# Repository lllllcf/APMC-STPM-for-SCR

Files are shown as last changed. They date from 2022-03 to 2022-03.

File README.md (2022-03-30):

# Spatial-temporal Programmable Metasurface for Single Channel Radiation

2021 APMC

Exploiting the spatial-temporal relationship, a novel programmable metasurface architecture is proposed to suppress undesired harmonics for spectrally efficient communication. A single-bit metasurface array with four-element unit cells is proposed to allow dynamic beamforming of the information metasurface without the use of phase shifters. The proposed method achieves an array factor with a harmonic suppression ratio of more than 15 dB. The meta-element design operates at a center frequency of 4.3 GHz with a bandwidth of 200 MHz, which can be exploited further to suppress higher-order harmonics. Using a carrier frequency of 4.2 GHz with a 100 MHz modulation signal, the proposed metasurface transmitting a signal with 50 MHz bandwidth can achieve an adjacent channel power ratio of -14.38 dB, indicating the feasibility of spatial-temporal programmable metasurface in practical communication applications.

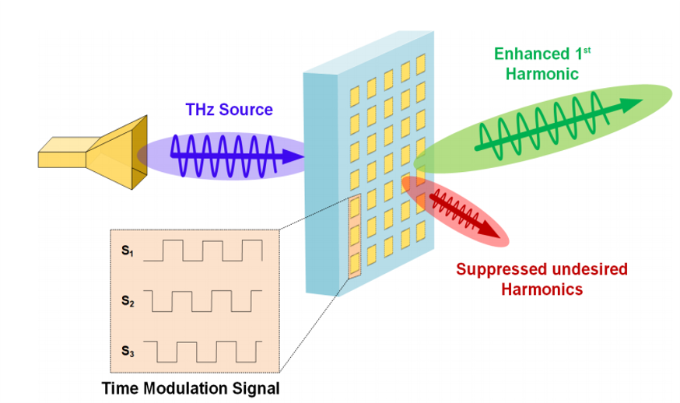
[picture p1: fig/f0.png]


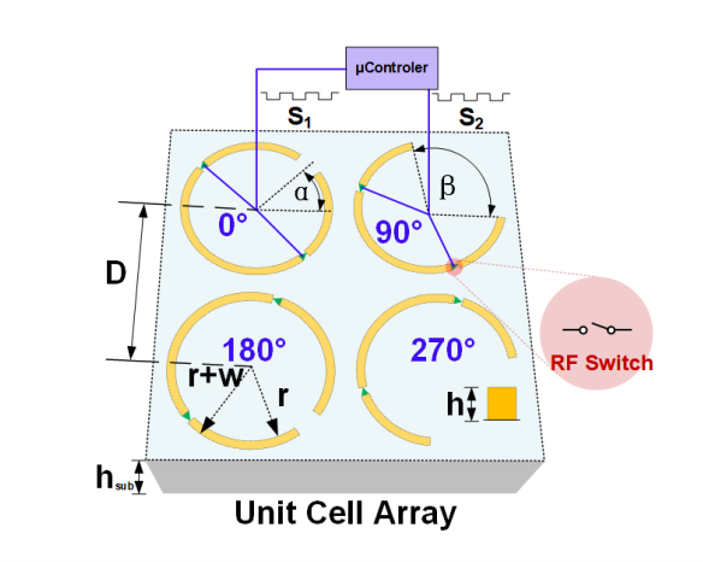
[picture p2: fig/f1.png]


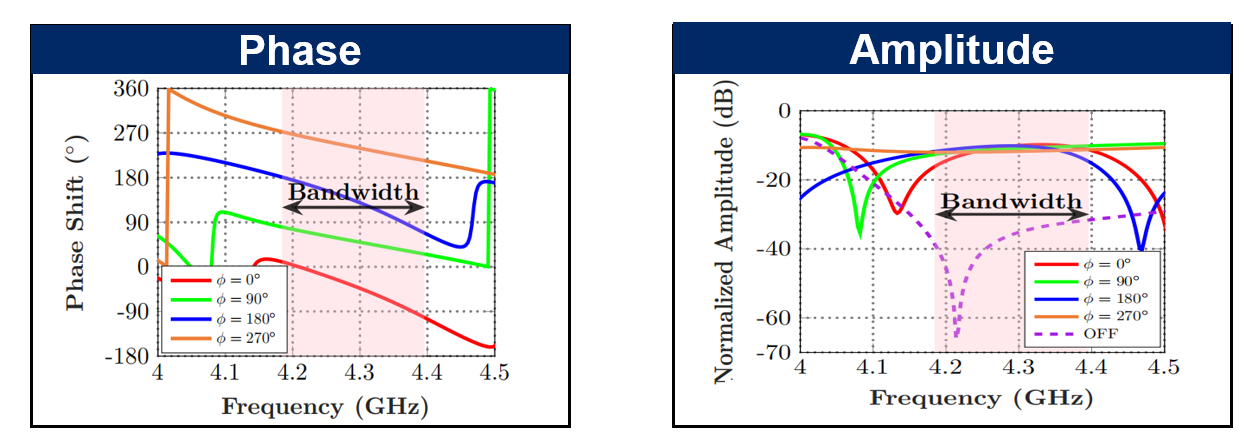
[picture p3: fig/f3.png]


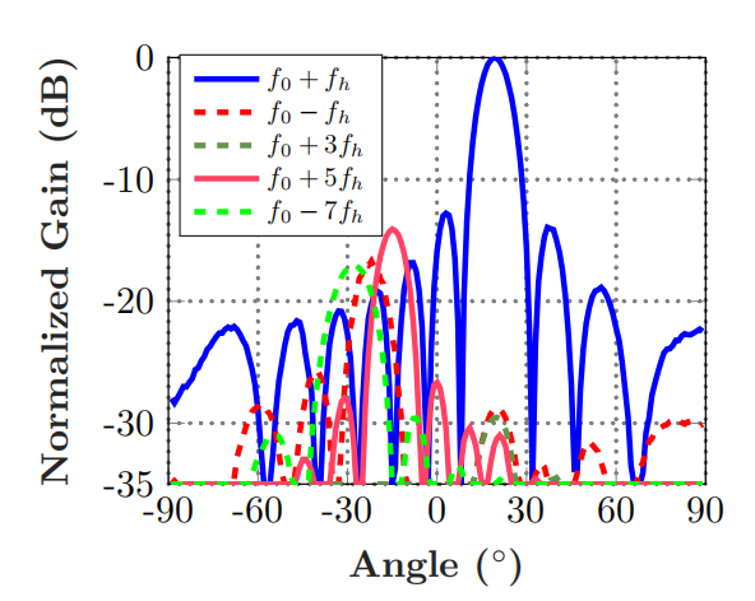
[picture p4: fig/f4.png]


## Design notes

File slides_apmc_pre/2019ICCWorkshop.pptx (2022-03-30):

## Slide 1

A Dynamic Array of Sub-Array Architecture for Hybrid Beamforming in the Terahertz Band

Longfei Yan, Chong Han, and Jinhong Yuan
Terahertz Wireless Communications laboratory
Shanghai Jiao Tong University
Email: longfei.yan@sjtu.edu.cn
Website: http://umji.sjtu.edu.cn/~chan/

## Outline

- Beamforming in the THz band
  - Hybrid (digital + analog)
- The Dynamic Array of Sub-Array (DAoSA) Hybrid Beamforming Architecture
- Summary

## The Terahertz Band

- Right after the mm-waves: from 0.1 to 10 THz
- Provides huge bandwidth: multiple GHz and even THz

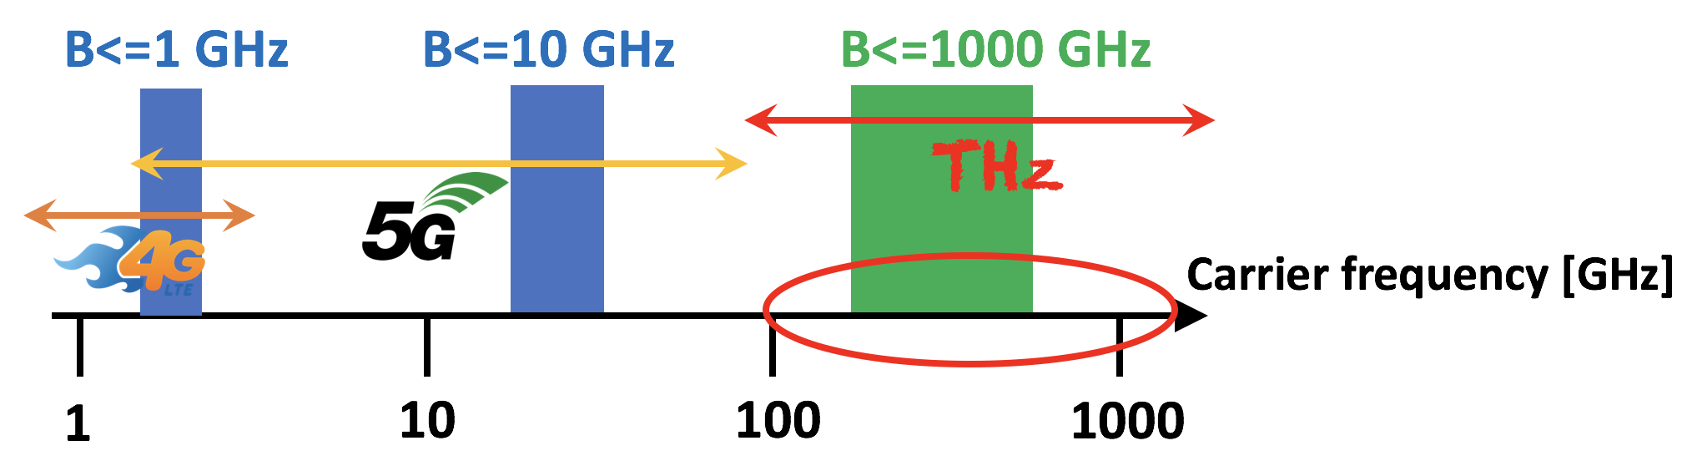
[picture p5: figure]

100 Gbps or even 1 Tbps is possible

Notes: Instead, lets take a look at the THz band, which lies right after the mm-wave. THz band is from 0.1 to 10 THz. It can provide multiple GHz and even THz bandwidth. This huge bandwidth of terahertz spectrum makes Tbps wireless link possible.

## Distance Challenge

I. F. Akyildiz, C. Han*, and S. Nie,
“Combating the Distance Problem in the Millimeter Wave and Terahertz Frequency Bands”,
IEEE Communications Magazine, 2018

- Distance limitation: a major challenge at THz frequencies is posed by the very high propagation loss
- Reasons:
  - Spreading loss
  - Molecular absorption loss
  - Reflection and scattering loss

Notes: Spreading loss: increases quadratically with the frequency, as defined by Friis’ law
Molecular absorption loss: part of the wave energy is converted into internal kinetic energy of the medium molecules (e.g., water-vapor)
Reflection and scattering loss: rough surface scattering arises with tens of dB losses

## Ultra-Massive MIMO

Frequency: f ↑

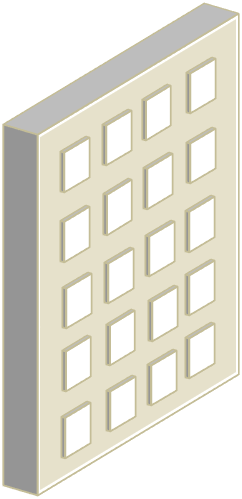
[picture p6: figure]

Smaller wavelength

More antennas

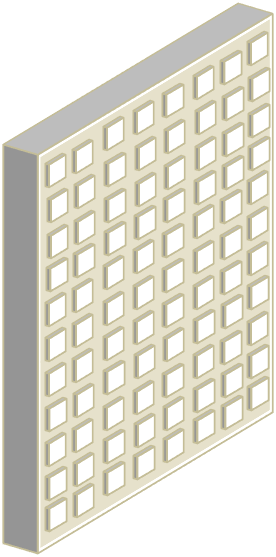
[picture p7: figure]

THz: f=1 THz, λ=0.3mm → Ultra-Massive MIMO, e.g., 256, 512 or even 1024 antennas at transmitter and receiver

Number of antennas: N ↑

How can we use these ultra-massive antennas to get benefits?

One solution is beamforming!

## Beamforming

Beamforming (BF) is to focus the radiated power of the antenna array into one or multiple directions.
Combined with the UM-MIMO system, the BF can provide:
- Array gain ∝ N_t N_r to increase the received SNR
- Spatial Multiplexing gain ∝ N_p to further enhance the spectral efficiency
- A Promising technology in THz wireless communications

## Why hybrid?

Digital beamforming: hardware & power consumption ✘

FPGA
+
DSP

FPGA
+
DSP

DAC

RF
Chain

RF
Chain

ADC

Channel
Matrix

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
Chain

RF
Chain

ADC

digital precoder

digital combiner

## Why hybrid?

Analog beamforming: performance & only single data stream ✘

Baseband

DAC

RF
Chain

N_t

Channel
Matrix

N_r

RF
Chain

ADC

Baseband

analog precoder

analog combiner

## Why hybrid?

Hybrid analog and digital beamforming:

FPGA
+
DSP

DAC

RF
Chain

Analog
signal
processing

analog precoder

N_s

L_t

DAC

RF
Chain

N_t

digital precoder

Analog
signal
processing

analog combiner

RF
Chain

FPGA
+
DSP

ADC

N_r

RF
Chain

L_r

ADC

N_s

digital combiner

Channel
Matrix

1≤L_r ≪ N_r

1≤L_t ≪ N_t

## Fully-Connected (FC)

FPGA
+
DSP

DAC

RF
Chain

RF
Chain

ADC

FPGA
+
DSP

N_t

Channel
Matrix

L_r

ADC

N_s

L_t

DAC

RF
Chain

N_r

RF
Chain

N_s

digital precoder

analog precoder

analog combiner

digital combiner

Each RF chain connects to all antennas through phase shifters.
The spectral efficiency can approach that of the digital beamforming.

O. E. Ayach, S. Rajagopal, S. Abu-Surra, Z. Pi, and R. W. Heath, “Spatially Sparse Precoding in Millimeter Wave MIMO Systems,” IEEE Trans. Wireless Commun, vol. 13, no. 3, pp. 1499–1513, March 2014.

## Array of Sub-array (AoSA)

FPGA
+
DSP

DAC

L_t

RF
Chain

N_t /L_t

N_r /L_r

RF
Chain

ADC

FPGA
+
DSP

Channel
Matrix

N_s

DAC

RF
Chain

N_t /L_t

N_t

N_r

N_r /L_r

RF
Chain

L_t

ADC

N_s

digital precoder

analog precoder

analog combiner

digital combiner

Each RF chain only connects to a sub-array through phase shifters.
Poor performance on spectral efficiency.

R. W. Heath and N. G.-P. et al, “An Overview of Signal Processing Techniques for Millimeter Wave MIMO Systems,”
IEEE J. Sel. Topics Signal Process, vol. 10, no. 3, pp. 436–453, April 2016.

## FC and AoSA architectures

- FC and AoSA

| Power consumption | Spectral efficiency
FC | Higher | Better
AoSA | Lower | poorer

Sacrifice either power consumption or spectral efficiency

Can we achieve a comparable spectral efficiency compared with FC while consuming much less energy?

Our solution: The dynamic array of sub-array (DAoSA) architecture

## Outline

- Beamforming in the THz band
  - Hybrid (digital + analog)
- The Dynamic Array of Sub-Array (DAoSA) Hybrid Beamforming Architecture
- Summary

## Dynamic Array of Sub-Array

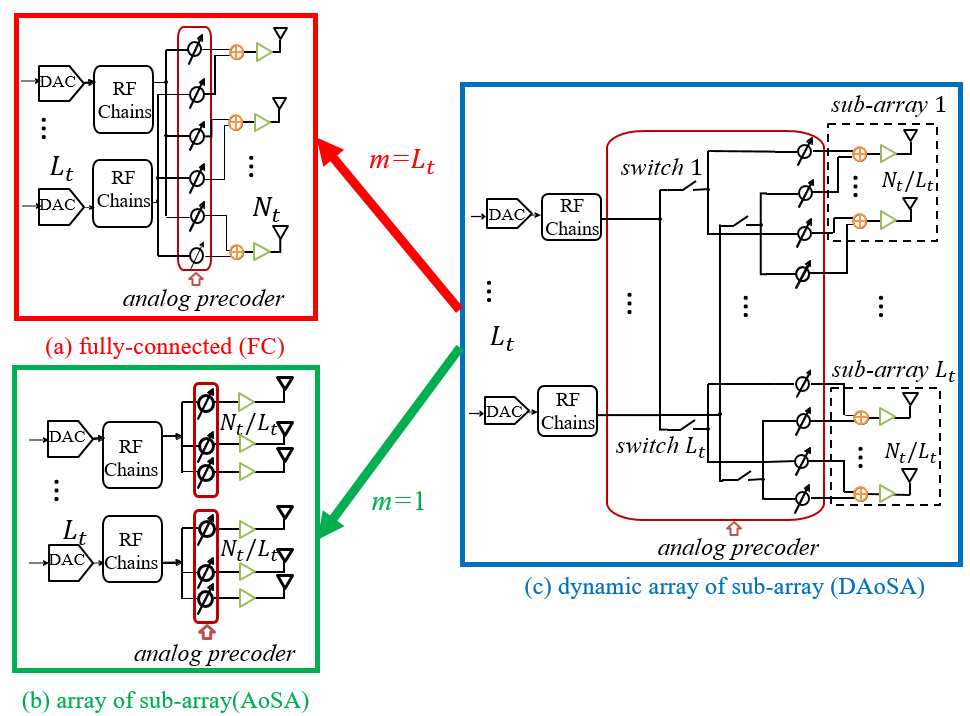
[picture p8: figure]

- Divide the antennas into L_t sub-arrays.
- Each RF chain connects to all the sub-arrays through L_t switches, but only m switches are closed.

- Antennas: N_t
- RF chains: L_t
- Switches: (L_t )^2
- Closed switches: m L_t
- Phase shifters: m N_t

## Problem Formulation

- Maximize the spectral efficiency
When assuming the Gaussian symbols, the spectral efficiency achieved by UM-MIMO systems can be stated as
- R_n =σ_n^2 C_D^H C_A^H C_A C_D is the covariance matrix of the noise vector after combining.
- The essence of solving this problem is finding proper P_A , P_D and C_A , C_D to maximize the spectral efficiency.

R=log_2 (|I_(N_s) +ρ/(N_s)R_n^(−1) C_D^H C_A^H HP_A P_D ×P_D^H P_A^H H^H C_A C_D | ),

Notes: After introducing the J2SMB system and the architecture, we are interested about the problem formulation and the solution of J2SMB system.

## Optimization Solution

Put the receiver optimal then optimize the transmitter side.
After designing the transmitter side, the receiver side can be designed as the same method.
P_A and P_D can be solved by

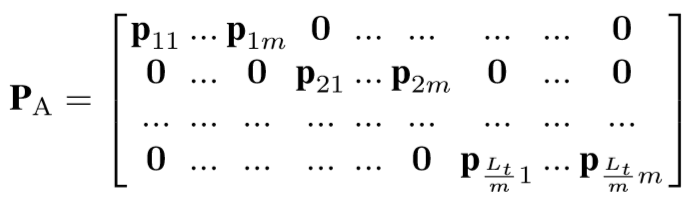
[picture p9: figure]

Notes: However, the joint optimization about transmitter and receiver is extremely difficult. To simplify the optimization process, first we make the assumption that the receiver is optimal so that we can focus on the design of transmitter. After determining the P_A and P_D , we solve the C_A and C_D . The optimization about transmitter and receiver is similar, so we give the optimization solution of P_A and P_D as an example and omit the optimization at receiver.

However, the joint optimization about transmitter and receiver is extremely difficult. To simplify the optimization process, first we make the assumption that the receiver is optimal so that we can focus on the design of transmitter. After determining the P_A and P_D, we solve the C_A and C_D. The optimization about transmitter and receiver is similar, so we give the optimization solution of P_A and P_D as an example and omit the optimization at receiver.

## Optimization Solution

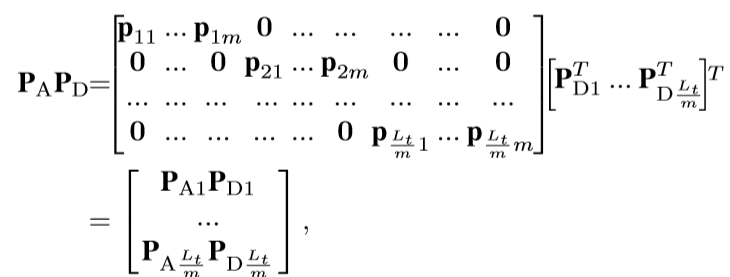
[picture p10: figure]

One intractable DAoSA problem has been decomposed into multiple tractable FC problems.
We just need to solve these FC problems one by one and then compose the ultimate solution.

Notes: However, the joint optimization about transmitter and receiver is extremely difficult. To simplify the optimization process, first we make the assumption that the receiver is optimal so that we can focus on the design of transmitter. After determining the P_A and P_D , we solve the C_A and C_D . The optimization about transmitter and receiver is similar, so we give the optimization solution of P_A and P_D as an example and omit the optimization at receiver.

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

## Performance Evaluation

- Simulation parameters

N_t = N_r =256, L_t = L_r =8, N_p ≤ 20, N_s =2 or 4

N_t and N_r : the number of antennas at transmitter and receiver
L_t and L_r : the number of RF chains at transmitter and receiver
N_p : the number of multi-path of the THz UM-MIMO channel
N_s : the number of data streams

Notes: Nt and Nr are the number of transmit antennas and receive antennas respectively. Lt and Lr are the number of RF chains at transmitter and receiver. Nray is the number of paths which make up the channel matrix H. m and n are the dynamic parameters of the DAoSA architecture.

## Power Consumption

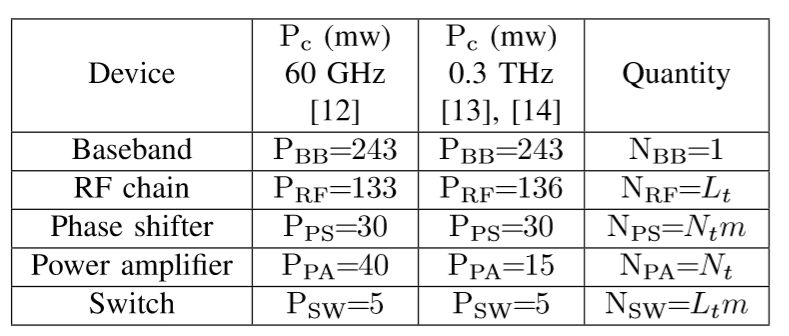
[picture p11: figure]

P_(total) =P_(BB) N_(BB) +P_(RF) N_(RF) +P_(PS) N_(PS) +P_(PA) N_(PA) +P_(SW) N_(SW)
= (a+b×m)%×P_total_FC
≈ (10 + 11m)% ×P_total_FC

## Spectral efficiency

DAoSA(Ns=4,m=4): similar SE, consume only 54% power

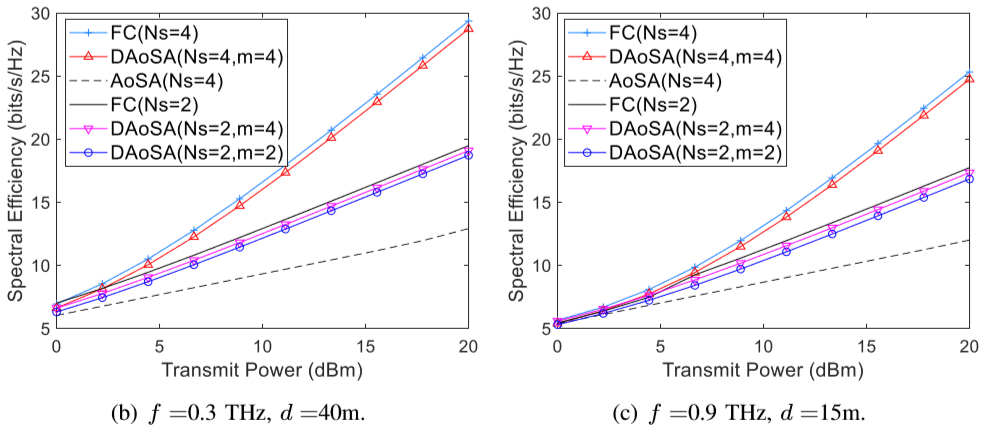
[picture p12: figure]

DAoSA(Ns=2, m=2):similar SE, consume only 32% power

The spectral efficiency of DAoSA is fairly closed to that of the FC and much higher than the AoSA.

(10 + 11m)% ×P_total_FC

## Outline

- Beamforming in the THz band
  - Hybrid (digital + analog)
- The Dynamic Array of Sub-Array (DAoSA) Hybrid Beamforming Architecture
- Summary

## Summary

Through selecting m intelligently, the spectral efficiency of DAoSA architecture is fairly closed to that of the FC, while consuming less power.
Compared with the AoSA architecture, the substantially higher spectral efficiency makes DAoSA more appealing.

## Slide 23

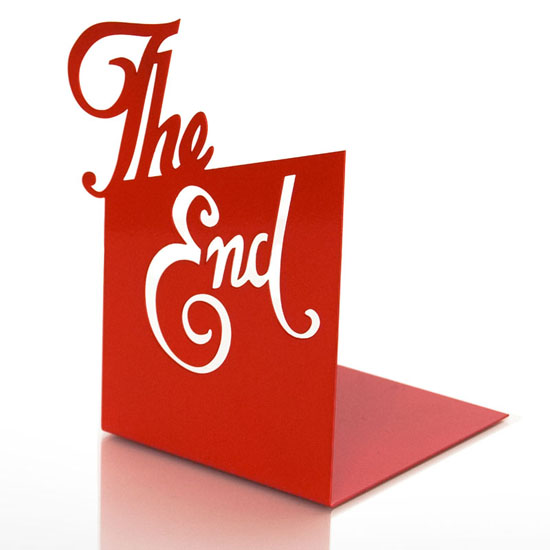
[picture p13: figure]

Mr. Longfei Yan
University of Michigan-Shanghai Jiao Tong University Joint Institute
Shanghai Jiao Tong University
Shanghai, 200240, China
Email: longfei.yan@sjtu.edu.cn
Website: http://umji.sjtu.edu.cn/~chan/

## CBC algorithm

Goal: minimize
Hint: there are l_t columns in P_(Ai) , N_s columns in P_(opti) .
First, divide the columns of P_(opti) into two groups. The exact group has l_t - N_s columns. The approximated group has 2 N_s - l_t columns.
Exact group: each column is exactly expressed as
Approximated group: each column is approximated as
Then, construct P_(Ai) and P_(Di) .

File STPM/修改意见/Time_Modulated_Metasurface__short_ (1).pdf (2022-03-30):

# High Efficiency beamforming Based on Time-Modulated Programmable Metasurface

Chengfan Li∗

, Zhehao Yu∗

, Yan Shen†

, Runqing Cai∗

, Xuyang Lu∗

∗UM-SJTU Joint Institute, Shanghai Jiao Tong University, Shanghai 200240, China †School of Electronics and Information Technology, Sun Yat-sen University, Guangzhou 510275, China Corresponding author: xuyang.lu@sjtu.edu.cn

Abstract—In this paper, a time-modulated programmable metasurface structure and its corresponding control strategy is designed to achieve beamforming and undesired harmonics suppression.
Index Terms—Beamforming, Harmonic Suppression, Programmable Metasurface, Time-Modulated Array.
I. Introduction

Recently, metasurfaces have attracted significant research interests due to its capability of tailoring the electromagnetic characteristics such as polarization, phase and amplitude at ease allows for the realization of beamforming [1] and frequency-division multiplexing [2]. As for metasurface beamforming, to make the control of EM waves more flexible, the active metasurface adds one or more switches on the metasurface structure, each switch brings two different states for active metasurface. More states means that the beam direction can be adjusted by switches, but it also increases the harmonic waves, leading to the efficiency degradation. Therefore, active metasurface faces the trade-off between flexibility and efficiency, especially in beamforming.
On the other hand, beamforming is achieved through the time-modulated array by exploiting time-domain signal processing techniques [3]. To achieve a low sideband level (SBL), the switching sequence can be designed such that a combination of signals modulated by those pulses will lead to suppression of undesired harmonics [4]. Therefore, it is a possible solution to construct flexible and efficient metasurface by applying the time modulation technique.
In this paper, as shown on Fig. 1, a time-modulated programmable metasurface (TMPM) is designed to receive external time modulation pulse signals to control the fast switching of each switch independently, so as to achieve beamforming and harmonic suppression. Each unit structure has four "ON" states with phase shift ϕ = (0, π
2

,π,

3π
2

)
and one "OFF" state with low transmittance. To apply time modulation method, a unit structure of four 1-bit metasurface unit cells are implemented to provide different phase shifts, and then combine them together to form a metasurface array.

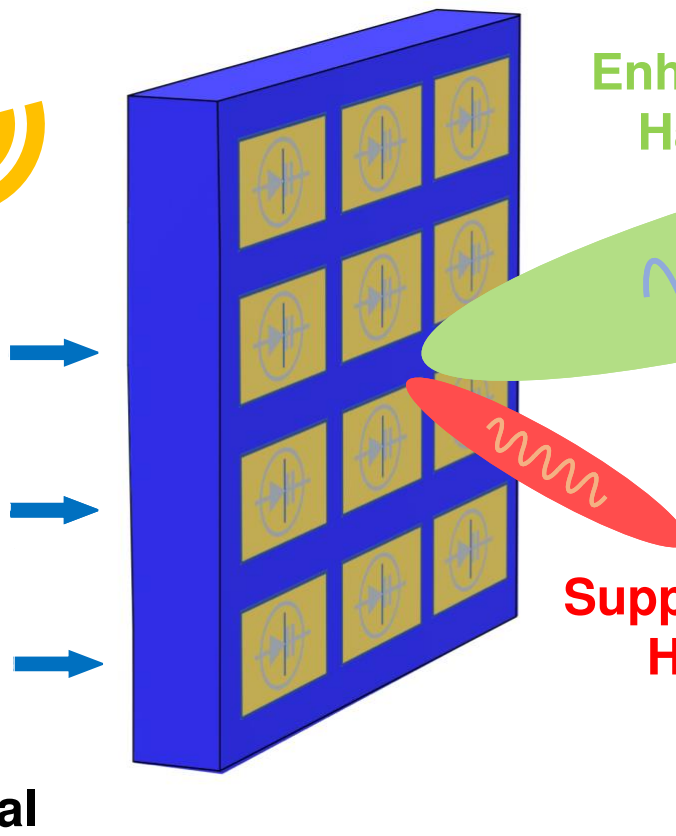
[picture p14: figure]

Suppressed other
Harmonics

Enhanced 1st
Harmonic

S1

S3

S2

Time Modulation Signal

Source

Fig. 1. Architecture of TMPM. Different time modulation signals are designed for each metasurface unit cell to achieve beamforming and suppress undesired harmonics.

II. Design and Theory
A. Time Modulated Metasurface Principle
To achieve high efficiency beamforming, time modulation control sequence for each switch should be designed. In this section, modulation sequence of metasurface with negligible inter-cell distance is first considered and then the impact of the distance is further calculated.
The length of each metasurface unit structure is defined as λ/D. As mentioned earlier, in ideal situation, each unit structure can be viewed as an array element which means that the distance λ/2D between two unit cells vanishes. Suppose that the origin is defined at the center of the bottom left unit structure and the whole metasurface totally have M rows and N columns, then the position of the unit structure on the mth row and n

th column under
the ideal case can be defined as
dmn = (mλ/D, nλ/D, 0). | (1)

Therefore, the array factor can be expressed as

AF(θ, ϕ, t) = f(t)

∑

M

m=1

∑

N

n=1

Imn · Umn

- e

j

2π
D sin θ[(m−1) cos ϕ+(n−1) sin ϕ]
(2)

where θ and ϕ defines the aimed angle for beamforming, ,f(t) denotes the incident wave, Imn is the transmittance for the unit structure on position dmn and Umn is the control function for the unit structure on position dmn. Because each unit structure contains four unit cells, Umn can be further expressed as

Umn = U

0
mn(t) + jU

π
2mn(t) − U

π
mn(t) − jU

3π
2mn(t) (3)

where U

0
mn(t), U

π
2mn(t), U

π
mn(t) and U

3π
2mn(t) are control
function on unit cell with different phases. Because those control functions consist of square wave, therefore U

i
| mn(i =
0,

π
2

, π, 3π
2

) can be further expressed as

Umn,i(t) = rect(

t − τ /2 − kTp − t

i
mn
τ
) | (4)

where Tp is the period of the switch control signal, τ is the time when the switch is on and t

i
mn is the time delay. The
four cells’ time delay and τ are designed as

t

π
2mn = t

0
mn +

Tp
4

t

π
mn = t

0
mn +

Tp
2

t

3π
2mn = t

0
mn −

Tp
4

τ =

Tp
3

(5)

where

t

0
mn = {

sin θ
D

[(m − 1) cos ϕ + (n − 1) sin ϕ] −

1
6

}Tp. (6)

To consider the impact of the interval between unit cells. A function f∆(x, y) can be defined to represent the time delay caused by the unit cell with position deviation (x, y) relative to the center of unit metasurface structures.

f∆(x, y) = |(x − 1) sin θ cos ϕ + (y − 1) sin θ sin ϕ − cos θ| − |sin θ cos ϕ + sin θ sin ϕ + cos θ| . (7)
For the relative position of the four unit cells related to the center of the unit metasurface structure is fixed, the advance of time can be defined as positive and the delay of time can be defined as negative. Therefore, f∆(x, y) can be modified into
f∆(x, y) = −x sin θ cos ϕ − y sin θ sin ϕ. | (8)

Then the equation for modifying the four tmn,i functions (i = 0,

π
2

, π, 3π
2

) can be simplified into a more general form with the value of τ remains unchanged.

t

i

′
mn = t

i
mn − f∆(xi
, yi) | (9)

where i = 0,

π
2

, π, 3π
2

and (xi

, yi) is the relative position of each unit cell, for example, (x0, y0) = (−

λ
4D

,

λ
4D

).

B. Unit Metasurface Structure Design
In this section, four 1-bit C-shape programmable metasurface unit cells with different phase responses are de-

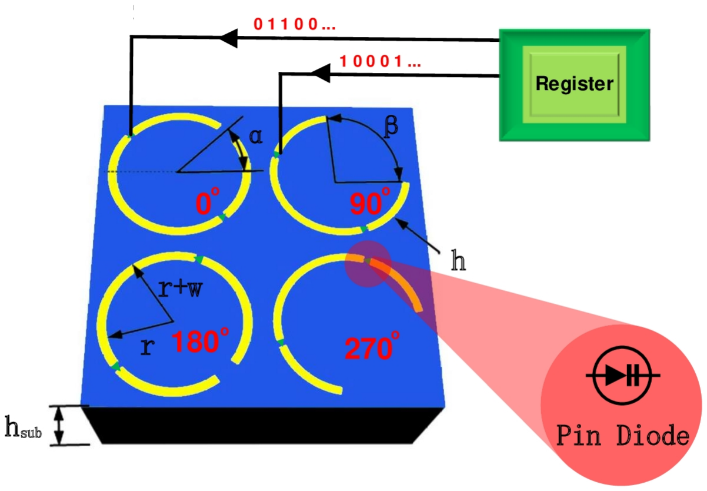
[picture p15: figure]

Fig. 2. Structure of C-shape metasurface unit structure with h={0.035, 0.018, 0.035, 0.018} mm, w={0.96, 0.84, 0.96, 0.84} mm, β={18, 108, 18, 108}◦, α={45, 45, -45, -45}◦, r=7.2 mm and hsub=16 mm. Here the four parameters of all the data correspond to the unit cell perform 0,

| π
| 2 , π, 3π
| 2 phase shift. Each unit cell contains two pin
diodes controlled by the time modulation signals.

signed and form a metasurface unit structure. The improved structure is shown on Fig. 2. On the top layer is four thin copper rings with height h, inner diameter r and thickness w. Under the ring is a substrate with thickness hsub, side length λ/D and dielectric constant 3.66. Two MA4AGFCP910 pin diodes produced by MACOM are added on each metal ring to realize the programmable function, and FPGA is used to control the fast switch of each unit cell independently to realize the time modulation. Through the design of opening angle β and orientation angle α towards the x-axis, phase modulation can be realized. When just one unit cell is opened, the unit structure produces phase response corresponding to that of the unit cell. Therefore, four "ON" states with different phase shifts can be achieved by open one unit cell and through closing all the pin diodes, "OFF" state can be produced.
Simulation results performed through CST Microwave Studio is shown on Fig. 3(a) and Fig. 3(b), which show the transmittance and phase shift responses of the unit structure. At the operating frequency, 4.21GHz, the simulation results show that there exists about 45dB difference on transmittance difference between four "ON" states and the ’OFF’, and four phases with separation of approximately
π
2

in the four "ON" states.

III. Simulation Result

Simulation is performed to validate the TMPM method with T=4, targeted angle ...◦ and operating frequency 4.21GHz. In order to simulate the ability of the TMPM to form beam and suppress spurious bands, a binary image is modulated and transmitted through the time modulated metasurface.
Fig. 3(c) gives a pictorial representation of the switch control signal of twelve metasurface unit cells at the posi-

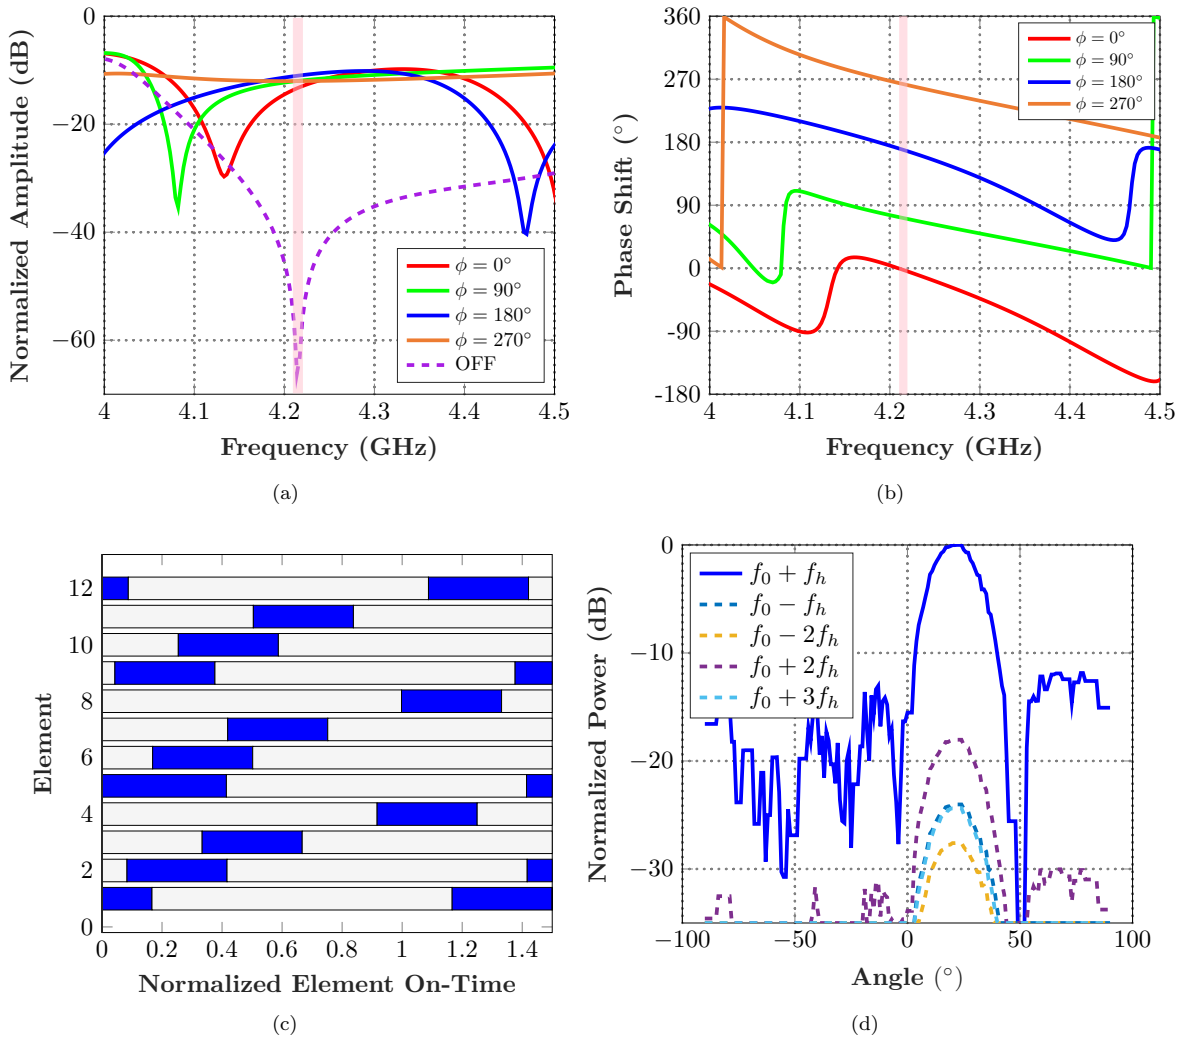
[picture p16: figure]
Frequency (GHz); Normalized Amplitude (dB); OFF; Phase Shift (; Normalized Element On-Time; Element; Angle (; Normalized Power (dB)

Fig. 3. Simulated characteristics of unit metasurface structure. (a) The S21 parameter of the five states. From 4.19GHz to 4.39GHZ, the S21 parameter for "ON" states is larger than -13dB and S21 parameter for the "OFF" state is less than -30dB. And the minimal amplitude response for "OFF" state is -66dB. (b) The four different phase shift responses. From 4.14GHz to 4.35GHz, the average relative error angle is less than 10◦. (c) The switch control signal for TMPM where blue means the pin diode is on. (d) Simulated radiation patterns for different harmonics generated by TMPM.

tion d11, d12 and d13. The periodicity of the switch control
signal and the offset between different unit structures can be clearly observed. Fig. 3(d) shows the normalized power on five different harmonics. The normalized power of the side band are all less than ...dB and the power of the 1st harmonic reaches the maximum at our target angle.

IV. Conclusion

In this paper, a time modulated programmable metasurface structure and its corresponding control strategy is designed to ensure both flexibility and efficiency of beamforming and spurious bands suppression. The validity of the metasurface structure containing four "ON" states with different phase responses and one "OFF" state with low transmittance is shown by CST simulation and the control strategy of the metasurface array is tested by MATLAB which shows accurate beamforming and effective harmonic suppression abilities.

References

[1] S. Liu, T. J. Cui, L. Zhang, Q. Xu, Q. Wang, X. Wan, J. Q. Gu, W. X. Tang, M. Qing Qi, J. G. Han et al., “Convolution operations on coding metasurface to reach flexible and continuous controls of terahertz beams,” Advanced Science, vol. 3, no. 10, p. 1600156, 2016.
[2] L. Zhang, M. Z. Chen, W. Tang, J. Y. Dai, L. Miao, X. Y. Zhou,
S. Jin, Q. Cheng, and T. J. Cui, “A wireless communication scheme based on space-and frequency-division multiplexing using digital metasurfaces,” Nature Electronics, vol. 4, no. 3, pp. 218– 227, 2021.

[3] H. Shanks and R. Bickmore, “Four-dimensional electromagnetic radiators,” Canadian Journal of Physics, vol. 37, no. 3, pp. 263– 275, 1959.
[4] A.-M. Yao, W. Wu, and D.-G. Fang, “Single-sideband time-modulated phased array,” IEEE Transactions on Antennas and Propagation, vol. 63, no. 5, pp. 1957–1968, 2015.

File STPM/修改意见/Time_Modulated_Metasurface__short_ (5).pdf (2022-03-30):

# High Efficiency beamforming Based on Time-Modulated Programmable Metasurface

Chengfan Li, Yan Shen, Zhehao Yu, Runqing Cai, Xuyang Lu

School of Electronics and Information Technology, Sun Yat-sen University, Guangzhou 510275, China UM-SJTU Joint Institute, Shanghai Jiao Tong University, Shanghai 200240, China. Corresponding author: xuyang.lu@sjtu.edu.cn

Abstract—In this paper, a time-modulated transmitive programmable metasurface structure and its corresponding control strategy is designed to achieve beamforming and spurious bands suppression.
Index Terms—Programmable Metasurface, Time-Modulated Array, Single-Sideband.
I. Introduction
Recently, metasurface have received wide attention due to its ability to manipulate electromagetic waves by controlling the polarization conversion, phase shift and amplitude response of electromagnetic waves. Many applications including beamforming, wireless communication, hologram and encryption have made great progress[...]. Focus on the area of metasurface beamforming, there are two kinds of metasurfaces: passive and active. Each unit of passive metasurface has only one response mode, so after periodic arrangement, the beam can only form on a specific direction. The active metasurface adds one or more switches on the metasurface structure, each switch brings two different states for active metasurface, and the formed wave can direct to many different directions. During this process, metasurface faces the trade-off between flexibility and efficiency, especially in beamforming. More states means that the beam direction can be adjusted by switches, but it also increases the harmonic waves, leading to the efficiency degradation.
So how to use active metasurface with less states to realize beamforming and suppress harmonics to ensure flexibility and efficiency at the same time becomes an important problem. In this context, beamforming achieved through the time-modulated array by exploiting timedomain signal processing techniques [1] becomes a potential solution. To achieve a low sideband level (SBL), the switching sequence can be designed such that a combination of signals modulated by those pulses will lead to suppression of undesired harmonics [2].
In this paper, as shown on Fig. 1, a time-modulated programmable metasurface (TMPM) is designed to receive external time modulation pulse signals to control the fast switching of each switch independently, so as to achieve beamforming and harmonic suppression. Each unit structure has four ’ON’ states with phase shift ϕ = (0, π
2

,π,

3π
2

)
and one ’OFF’ state with low transmittance. To apply

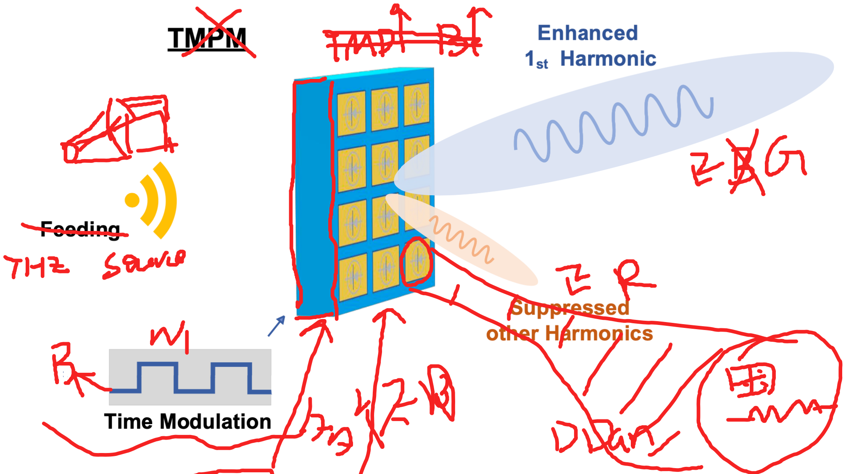
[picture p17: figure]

Fig. 1. Architecture of TMPM.

time modulation method, a unit structure of four 1-bit metasurface unit cells are implemented to provide different phase shifts, and then combine them together to form a metasurface array.

II. Design and Theory

A. Time Modulated Metasurface Principle

To achieve high efficiency beamforming, time modulation control sequence for each switch should be design. In this section, modulation sequence of metasurface with negligible inter-cell distance will first be considered and then the impact of the distance will be further calculated. The length of each metasurface unit structure is defined as λ/D. As mentioned earlier, in ideal situation, each unit structure can be viewed as an array element which means that the distance λ/2D between two unit cells vanishes. Suppose that the origin is defined at the center of the bottom left unit structure and the whole metasurface totally have M rows and N columns, then the position of the unit structure on the mth row and n

th column under
the ideal case can be defined as
dmn = (mλ/D, nλ/D, 0). | (1)

So the array factor can be written as

AF(θ, ϕ, t) = f(t)

∑

M

m=1

∑

N

n=1

Imn · Umn

- e

j

2π
D sin θ[(m−1) cos ϕ+(n−1) sin ϕ]
(2)
where θ and ϕ defines the aimed angle for beamforming, ,f(t) denotes the incident wave, Imn is the transmittance for the unit structure on position dmn and Umn is the control function for the unit structure on position dmn. Because each unit structure contains four unit cells, Umn can be further written as

Umn = U

0
mn(t) + jU

π
2mn(t) − U

π
mn(t) − jU

3π
2mn(t) (3)

where U

0
mn(t), U

π
2mn(t), U

π
mn(t) and U

3π
2mn(t) are control
function on unit cell with different phases.
The control signal consists of square wave so that the control functions U

i
mn(i = 0,

π
2

, π, 3π
2

) can be further
writtern as

Umn,i(t) = rect(

t − τ /2 − kTp − t

i
mn
τ
) | (4)

where Tp is the period of the switch control signal, τ is the time when the switch is on and t

i
mn is the time delay.
For each unit structure, the four cells’ time delay and τ can be writtern as

t

π
2mn = t

0
mn +

Tp
4

t

π
mn = t

0
mn +

Tp
2

t

3π
2mn = t

0
mn −

Tp
4

τ =

Tp
3
where

t

0
mn = {

sin θ
D

[(m − 1) cos ϕ + (n − 1) sin ϕ] −

1
6

}Tp. (5)

To consider the impact of the interval between unit cells. A function can be defined f∆(x, y) to represent the time delay caused by the unit cell position deviation (x, y).

f∆(x, y) = |(x − 1) sin θ cos ϕ + (y − 1) sin θ sin ϕ − cos θ| − |sin θ cos ϕ + sin θ sin ϕ + cos θ| . (6)

For the relative position of the four unit cells related to the center of the unit metasurface structure is fixed, we can suppose that the advance of time is defined as positive and the delay of time is defined as negative. So that f∆(x, y) can be modified into

f∆(x, y) = −x sin θ cos ϕ − y sin θ sin ϕ. | (7)

Then the equation for modifying the four tmn,i functions (i = 0,

π
2

, π, 3π
2

) can be simplified into a more general form.

And the value of τ remains unchanged.

t

i

′
mn = t

i
mn − f∆(xi
, yi) | (8)

where i = 0,

π
2

, π, 3π
2

, (xi

, yi) is the relative position of each unit cell, for example, (x1, y1) = ( λ
4D

,

λ
4D

).

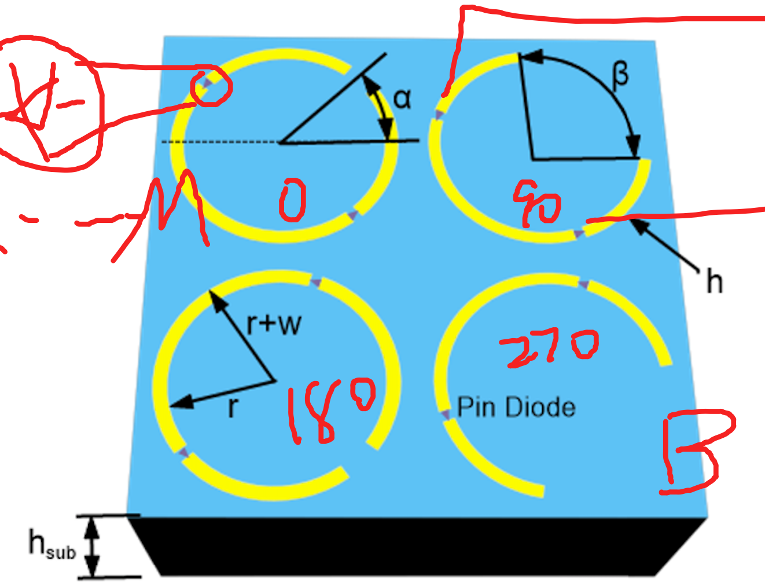
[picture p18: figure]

Fig. 2. Structure of C-shape metasurface unit structure with h={0.035, 0.018, 0.035, 0.018} mm, w={0.96, 0.84, 0.96, 0.84} mm, β={18, 108, 18, 108} ◦, α={45, 45, -45, -45} ◦, r=7.2 mm and hsub=16 mm. Here the four parameters of all the data correspond to the unit cell perform 0, π

| 2 ,π, 3π
| 2 phase shift.
B. Unit Metasurface Structure Design
In this section, four 1-bit C-shape programmable metasurface unit cells are designed and form a metasurface unit structure. The improved structure is shown on Fig.
2. On the top layer is four thin copper rings with height h, inner diameter r and thickness w. Under the ring is a substrate with thickness hsub, side length λ/D and dielectric constant 3.66 Two MA4AGFCP910 pin diodes produced by MACOM are added on each metal ring to realize the programmable function, and FPGA is used to control the fast switch of each unit cell independently to realize the time modulation. Through the design of opening angle β and orientation angle α towards the xaxis, phase modulation can be realized.
Simulation results performed through CST Microwave Studio is shown on Fig. 3, which shows the transmittance and phase shift responses of the unit structure. At the operating frequency, 4.21GHz, the simulation results show that there exists about 45dB difference on transmittance difference between four ’ON’ states and the ’OFF’, and four phases with separation of approximately π
| 2

in the four
’ON’ states.

III. Simulation Result
Simulation is performed to validate the TMPM method with T=4, targeted angle 20◦ and operating frequency 4.21GHz. In order to simulate the ability of the TMPM to form beam and suppress spurious bands, a binary image is modulated and transmitted through the time modulated metasurface.
Fig. ?? gives a pictorial representation of the switch control signal of twelve metasurface unit cells at the position d11, d12 and d13. The periodicity of the switch control signal and the offset between different unit structures can

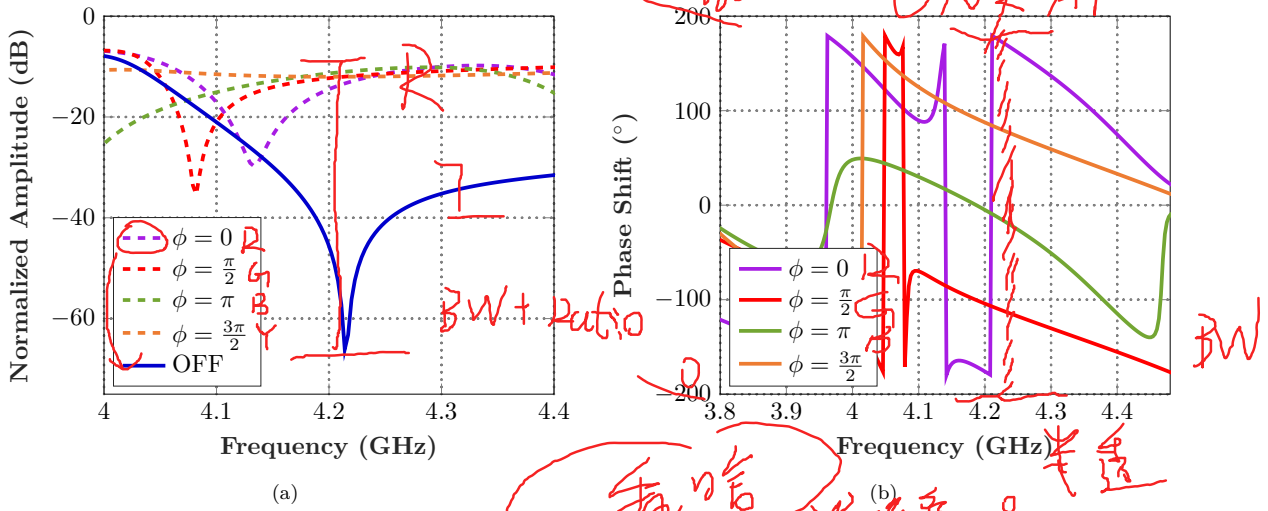
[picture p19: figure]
Frequency (GHz); Normalized Amplitude (dB); OFF; Phase Shift (

2 | 4 | 6 | 8 | 10 | 12

0

0.5

1

1.5

Element

Normalized Element On-Time

(c)

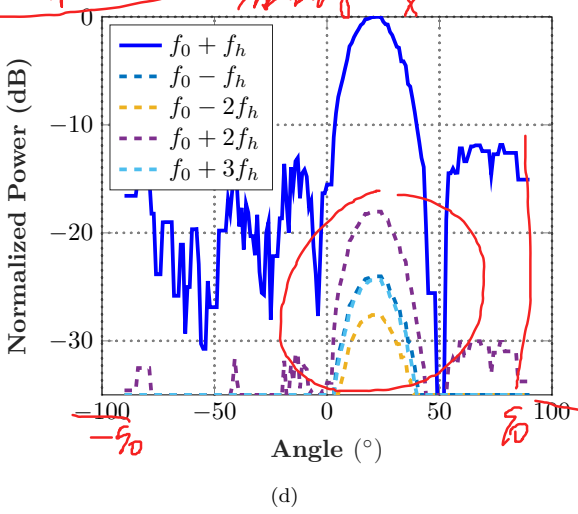
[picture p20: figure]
Angle (; Normalized Power (dB)

Fig. 3. Simulated characteristics of unit metasurface structure. (a) The S12 parameter of the five states. (b) The four different phase shift responses.

be clearly observed. Fig. ?? shows the normalized power
on five different harmonics. The normalized power of the side band are all less than -18dB and the power of the 1st harmonic reaches the maximum at our target angle.

IV. Conclusion
In this paper, a time modulated transmitive programmable metasurface structure and its corresponding control strategy is designed to achieve beamforming and spurious bands suppression. The CST simulation is provided to ensure the validity of the characteristic of the structure and the Matlab is used to test the control strategy of the metasurface array. Both the two simulation shows excellent results in line with our expectation.....be specificc Introducing time modulation into metasurface can ensure the flexibility and efficiency of beamforming, namely, use less states for each unit cell to perform more complex functions.to solve blabla problem, TM technique blabla

References

[1] H. Shanks and R. Bickmore, “Four-dimensional electromagnetic radiators,” Canadian Journal of Physics, vol. 37, no. 3, pp. 263– 275, 1959.
[2] A.-M. Yao, W. Wu, and D.-G. Fang, “Single-sideband time-modulated phased array,” IEEE Transactions on Antennas and Propagation, vol. 63, no. 5, pp. 1957–1968, 2015.

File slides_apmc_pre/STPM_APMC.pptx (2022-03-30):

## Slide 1

- S3-07

- Spatial-temporal Programmable Metasurface for Single Channel Radiation

C. Li¹, Z. Yu¹, Y. Shen², R. Cai¹, and X. Lu¹
¹UM-SJTU Joint Institute, Shanghai Jiao Tong University, Shanghai, China
²School of Electronics and Information Technology, Sun Yat-sen University, Guangzhou, China

1

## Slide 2

- Introduction
- Unit Cell Design
- Harmonic Suppression Theory
- Simulation Result
- Conclusion and Discussion

Outline

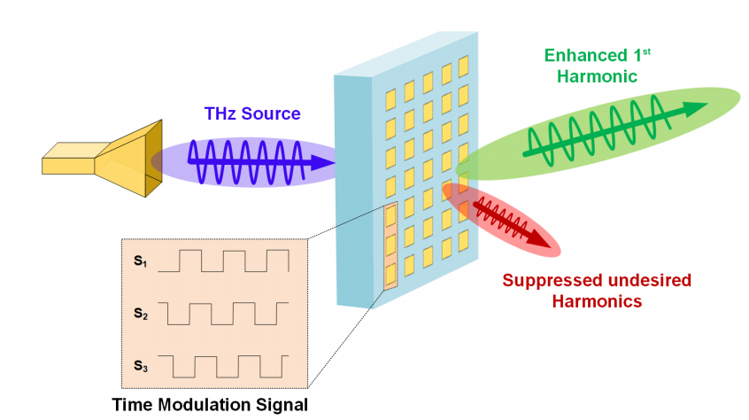
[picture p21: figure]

2

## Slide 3

Introduction

2

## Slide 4

Unit Cell Design

2

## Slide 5

Harmonic Suppression Theory

2

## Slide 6

Simulation Result

2

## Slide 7

Conclusion

2

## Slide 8

Discussion

2

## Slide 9

Reference

2

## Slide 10

Q & A

2

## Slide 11

Thank You

2

## Spatial-temporal Programmable Metasurface for Single Channel Radiation

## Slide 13

- Background
- Unit Cell Design
- Harmonic Suppression Theory, （耦合，固定一者周边不是复制，观察变化，仿真， spacing的变化导致系数的变化， 开关瞬间、噪声的影响，时间抖动影响）
- Simulation Result
- Conclusion and Discussion

## Background，参照bilibili

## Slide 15

Coding metasurface

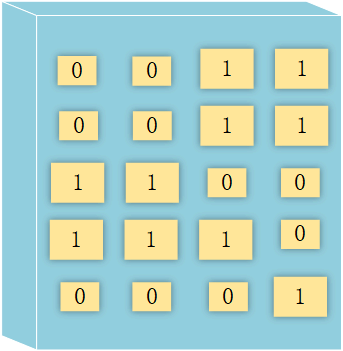
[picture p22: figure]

Programmable metasurface

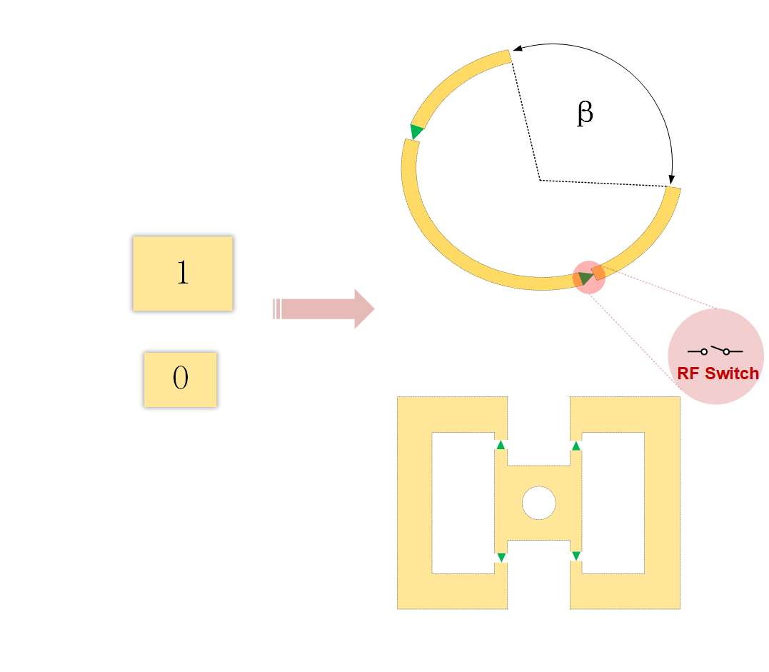
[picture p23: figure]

- 设计开关以获得需要的状态（phase,amplitude, polarization）。用FPGA编码超表面。
- 灵活，任意控制
- 设计与制造困难。Hard to achieve continously tunable phase，面临Phase granularity and radiation efficiency
的trade off，multilayer？

- Coding sequence设计容易，原理成熟，排布模式的推导容易。制造便捷，便宜，无源无控制系统
- 散射模式固定，或许可以拼装，但大多低频。好处是，设计起来容易，尺寸太大

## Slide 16

Spatial-temporal Programmable Metasurface

- 引入第四个变量，解决连续编码的限制
- 实现相位的控制的同时，减小损耗
- 单层材料的调相理论极限
- 可调节的相位比特数越多，损耗越大，波束赋形效果越好，但是传输距离变短了。
- 时间上的调控引入了更多的谐波，所以需要采取手段消除谐波

## 应用

- 谐波消除 高效通信 波束赋形 space- and frequency-division multiplexing
- 可移植，多用途，灵活高效the flexibility for installation, and low cost

## Unit Cell Design

## Four 1-bit elements Five States one off state 低透过率 four on states 高透过率并提供四种相位变化来替代phase shifters 8 pin diodes，由高速FPGA控制

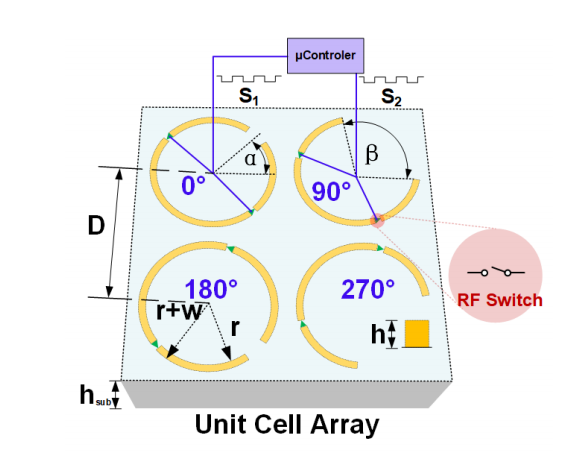
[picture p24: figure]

## Phase and Amplitude modulation

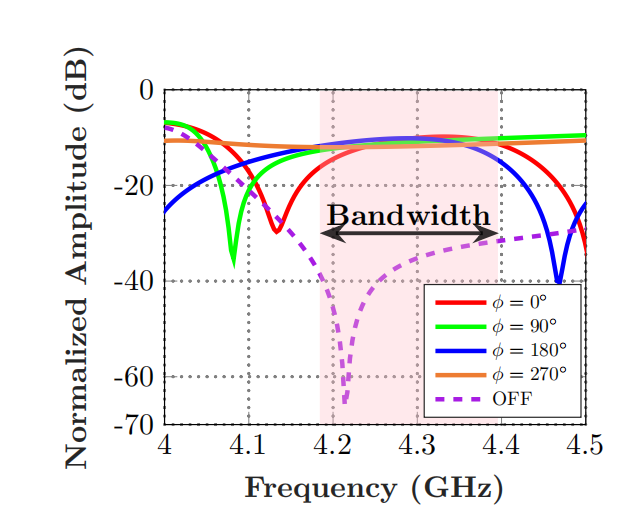
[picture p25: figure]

S21 parameter
4.3GHz, 200MHz bandwidth D=lambda/8
On-off ratio > 20dB, average 27.6dB
Transmittance > -12dB, off state < -30dB

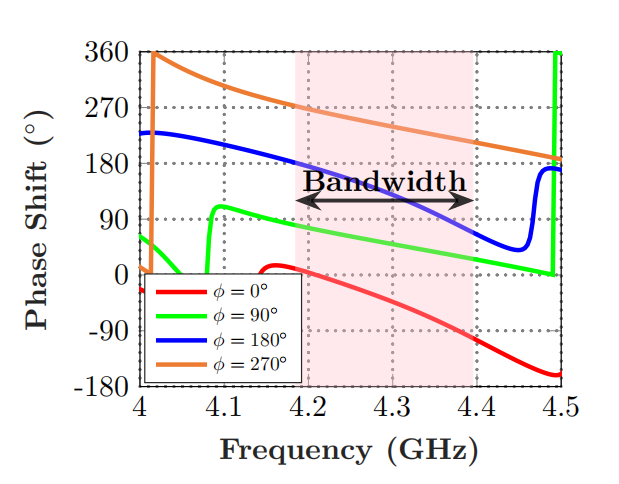
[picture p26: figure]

Relative phase error less than 10 \deg

## Harmonic Suppression Theory

## Phased Array

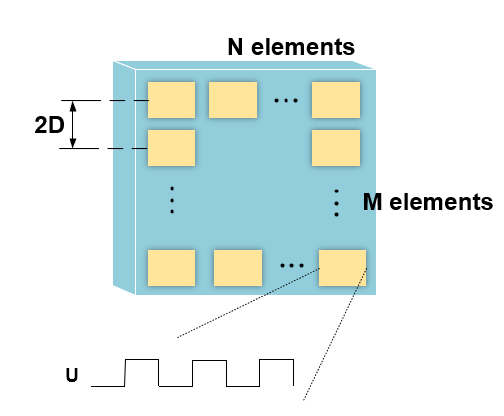
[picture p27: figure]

## STPM

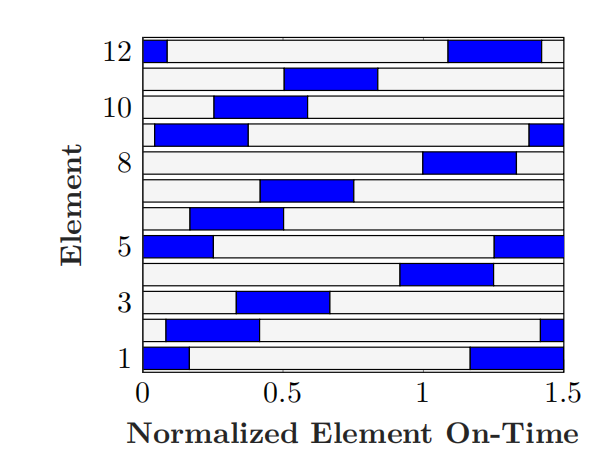
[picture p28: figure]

## Simulation Result

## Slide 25


Harmonic suppression ratio of more than 15dB
Adjacent channel power ratio of -14,38dB
Target angle 20 \deg

## Conclusion and Discussion

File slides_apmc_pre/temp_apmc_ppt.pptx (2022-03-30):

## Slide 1

Spatial-temporal Programmable Metasurface for
Single Channel Radiation

## 上海交通大学PPT模板（学术）

2016年4月

## 标题页第二版以及应用实例（学术）

主讲人姓名

- 2016年4月

## 目录 Contents

1

说明

2

无页码版式

3

有页码版式

4

图形与配色

5

图片处理及排版

## 目录 Contents

1

说明

2

无页码版式

3

有页码版式

4

图形与配色

5

图片处理及排版

## 关于模板的使用说明

- 点击开始-新增幻灯片的下拉按钮可以看到本PPT所包含的版式。
- 版式分为有页码版和没有页码版，供使用者选择。其中有页码的版式会自动添加页码。


## 关于模板的使用说明

- 请在设计菜单卡的下拉列表里可以选择保存当前主题。下次使用时即可在设计菜单中直接调用主题设置。
- 字体使用的是等线字体，系统升级为WIN10后自动安装。如系统尚未升级可以尝试微软雅黑字体。配色使用的是VI辅助色系。


## 目录 Contents

1

说明

2

无页码版式

3

有页码版式

4

图形与配色

5

图片处理及排版

## 标题内容标题内容

- 文字内容文字内容文字内容文字内容
  - 文字内容文字内容文字内容文字内容文字内容
  - 文字内容文字内容文字内容文字内容文字内容
- 文字内容文字内容文字内容文字内容

## 纯标题页面标题内容

## 极简版内页

- 极简版内页去除了题图，换以纯色背景；
- 供内页内容较为复杂时使用，可以避免复杂图片对内容呈现的干扰；
- 供PPT使用场合较为严肃，不适合复杂图片出现的情况下。
- 如需使用，建议PPT所有内页均使用极简版式，可以达到更简洁清爽的效果。

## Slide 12

空白页面，可供大型图表、图片排版
此文本框仅为注释，制作时请删除

## 标题内容标题内容

- 第一栏内容第一栏内容第一栏内容第一栏内容第一栏内容第一栏内容
- 第一栏内容第一栏内容第一栏内容第一栏内容第一栏内容第一栏内容
- 第一栏内容第一栏内容第一栏内容第一栏内容第一栏内容第一栏内容

- 第二栏内容第二栏内容第二栏内容第二栏内容第二栏内容第二栏内容
- 第二栏内容第二栏内容第二栏内容第二栏内容第二栏内容第二栏内容
- 第二栏内容第二栏内容第二栏内容第二栏内容第二栏内容第二栏内容

## 比较内容标题

- 比较内容比较内容比较内容
- 比较内容比较内容比较内容
- 比较内容比较内容比较内容
- 比较内容比较内容比较内容
- 比较内容比较内容比较内容

- 比较内容比较内容比较内容
- 比较内容比较内容比较内容
- 比较内容比较内容比较内容
- 比较内容比较内容比较内容
- 比较内容比较内容比较内容

- 比较内容标题

## 目录 Contents

1

说明

2

无页码版式

3

有页码版式

4

图形与配色

5

图片处理及排版

## 标题内容标题内容

- 文字内容文字内容文字内容文字内容
  - 文字内容文字内容文字内容文字内容文字内容
  - 文字内容文字内容文字内容文字内容文字内容
- 文字内容文字内容文字内容文字内容

## 纯标题页面标题内容

## 极简版内页-有页码

- 极简版内页去除了题图，换以纯色背景；
- 供内页内容较为复杂时使用，可以避免复杂图片对内容呈现的干扰；
- 供PPT使用场合较为严肃，不适合题图复杂图片出现的情况下。
- 如需使用，建议所有内页均使用极简版式，以达到更简洁、清爽的效果。

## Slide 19

空白页面，可供大型图表、图片排版
此文本框仅为注释，制作时请删除

## 标题内容标题内容

- 第一栏内容第一栏内容第一栏内容第一栏内容第一栏内容第一栏内容
- 第一栏内容第一栏内容第一栏内容第一栏内容第一栏内容第一栏内容
- 第一栏内容第一栏内容第一栏内容第一栏内容第一栏内容第一栏内容

- 第二栏内容第二栏内容第二栏内容第二栏内容第二栏内容第二栏内容
- 第二栏内容第二栏内容第二栏内容第二栏内容第二栏内容第二栏内容
- 第二栏内容第二栏内容第二栏内容第二栏内容第二栏内容第二栏内容

## 比较内容标题

- 比较内容比较内容比较内容
- 比较内容比较内容比较内容
- 比较内容比较内容比较内容
- 比较内容比较内容比较内容
- 比较内容比较内容比较内容

- 比较内容比较内容比较内容
- 比较内容比较内容比较内容
- 比较内容比较内容比较内容
- 比较内容比较内容比较内容
- 比较内容比较内容比较内容

- 比较内容标题

## 目录 Contents

1

说明

2

无页码版式

3

有页码版式

4

图形与配色

5

图片处理及排版

## 可仅使用蓝色

标题内容
标题内容
标题内容
文字内容文字内容
文字内容文字内容
文字内容文字内容
文字内容文字内容
文字内容文字内容
文字内容文字内容

## 可使用多色搭配

- 请使用本主题包含的交大VI指定配色；

此图示仅为示例

此图示仅为示例

此图示仅为示例

此图示
仅为示例

此图示
仅为示例

此图示
仅为示例

此图示
仅为示例

此图示
仅为示例

## 可使用VI辅助图形

可作为ICON或形状，如：

1

注：

可作为分割线，如：

文字内容

文字内容

文字内容

文字内容

文字内容

文字内容

文字内容

文字内容

文字内容

文字内容

文字内容

文字内容

## 目录 Contents

1

说明

2

无页码版式

3

有页码版式

4

图形与配色

5

图片处理及排版

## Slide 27


注：


- 使用辅助图形增加图片边。
- 本页图片处理的方式仅供参考，非指定样式。
- 仅为方便使用，本页PPT中所有的图片均为3:2主流图片比例。如需更精确的PPT制作或其他设计，请根据设计标准对图片进行剪裁。

## 谢谢！

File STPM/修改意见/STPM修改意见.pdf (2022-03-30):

# Spatial-temporal Programmable Metasurface for Single Channel Radiation

Chengfan Li∗

, Zhehao Yu∗

, Yan Shen†

, Runqing Cai∗

, Xuyang Lu∗
∗UM-SJTU Joint Institute, Shanghai Jiao Tong University, Shanghai 200240, China † School of Electronics and Information Technology, Sun Yat-sen University, Guangzhou 510275, China Corresponding author: Xuyang.Lu@sjtu.edu.cn

Abstract—Exploiting the spatial-temporal relationship, a novel programmable metasurface architecture is proposed to suppress undesired harmonics for spectrally efficient communication. A single-bit metasurface array with four-element unit cells is proposed to allow dynamic beamforming of the information metasurface without the use of phase shifters. The proposed method achieves an array factor with a harmonic suppression ratio of more than 15 dB. The meta-element design operates at a center frequency of 4.205 GHz with a bandwidth of 50 MHz, which can be exploited further to suppress higher-order harmonics. Using a carrier frequency of 4.21 GHz with a 50 MHz modulation signal, the proposed metasurface transmitting a signal with 15 MHz bandwidth can achieve an adjacent channel power ratio of 33.4 dB, indicating the feasibility of spatial-temporal programmable metasurface in practical communication applications.
Index Terms—space-time coding, beamforming, harmonic suppression, programmable metasurface, intelligent reflecting surface.
I. Introduction

Recently, programmable intelligent surfaces attract increasing research interests due to their capability of tailoring the electromagnetic characteristics of wireless signals on the fly to allow a simplified realization of beamforming [1]. Thanks to the merits of programmable metasurfaces including low power consumption, the flexibility for installation, and low cost, extensive implementation of those surfaces can significantly enhance the quality of wireless communication channels by exploiting both the temporal and spatial domain multiplexing, and thus is considered a promising candidate for mmWave 5G communication.
Ideal beamforming requires the metasurface to present a continuously tunable phase, which greatly limits the number of feasible low-cost solutions. Nevertheless, metasurface suffers a tradeoff between phase granularity and radiation efficiency. For a double layer structure, a 50◦ of flexibility on phase shift reduces the transmission by at least 2 dB [2]. On the other hand, although meta-element provides a discrete subset of amplitude and phase combinations, a meticulously-designed time-varying modulating sequence is applied to each meta-elements to facilitate granular beamforming [3]. Nevertheless, the adoption of time-domain modulation can be interpreted as a frequency


Fig. 1. Architecture of STPM. Different time modulation signals are designed for each metasurface unit cell to achieve beamforming and suppress undesired harmonics.

domain convolution of the original narrowband signal with the Fourier sequence of the modulating pulses, which inevitably introduces frequency harmonics. Despite its potential application in broadcasting and secured communication, frequency harmonics are in general undesired as it contaminates neighboring channels.
In this work, as shown in Fig. 1, we propose a Spatial-Temporal Programmable Metasurface (STPM) architecture as a potential solution for intelligent beamformers that can achieve spectral and radiation efficiency simultaneously. The unit-cell design contains four programmable 1-bit meta-element whose switching patterns are designed to achieve beamforming and harmonic suppression at the same time. In section II-A, the mathematical foundation of the proposed STPM array is presented to account for the physical arrangement of unit cells. In section II-B, the optimization of the unit cell design is presented. The frequencydependent transmission features of the meta-element is further utilized to suppress high-order harmonics, and the collective effect of array synthesis and element design is presented in section III.

II. STPM Array Principle and Unit-cell Design

A. Harmonic Suppression in a STPM

A classical method in signal processing to suppress harmonics is to exploit the property of Hilbert transformation by properly combine a signal with its quadrature duo. Inspired by this method, we design a metasurface unit array that is capable of transmitting four different phases, and the modulating sequences are to be designed

dmn = (mD, nD, 0). | (1)

Therefore, the array factor can be expressed as

AF(θ, ϕ, t) = f(t)

∑

M

m=1

∑

N

n=1

Imn · Umn

- e

j

2πD
λ

sin θ[(m−1) cos ϕ+(n−1) sin ϕ]
,

(2)

where θ and ϕ define the target angle for beamforming, f(t) denotes the incident wave, Imn and Umn is the transmittance and control function for the unit structure on position dmn. Because each unit structure contains four unit cells, Umn can be further expressed as

Umn = U

0
mn(t) + jU

π
2mn(t) − U

π
mn(t) − jU

3π
2mn(t), (3)

where U

0
mn(t), U

π
2mn(t), U

π
mn(t) and U

3π
2mn(t) are control
functions on unit cell with different phases. Since those modulating waveforms are composed of rectangular pulses with distinct switch-on time, U

i
mn(i = 0,

π
2

, π, 3π
2

) can be
further expressed as

Umn,i(t) = rect(t − τ /2 − kTp − t

i
mn
τ

), (4)

where Tp is the period of the switch control signal, τ is the time length of the "ON" state and t

i
mn is the time delay.
The time delay of the four cells and τ are optimized as t

π
2mn = t

0
mn +

Tp
4

; t

π
mn = t

0
mn +

Tp
2

; t

3π
2mn = t

0
mn −

Tp
4
| and
τ =

Tp
3

, where

t

0
mn = {

sin θD
λ

[(m − 1) cos ϕ + (n − 1) sin ϕ] −

1
6

}Tp. (5)

We further consider the impact of the displacement between unit cell elements. One realization of the unit cells is illustrated in Fig. 2. Here we analyze the effect of array space D/2 between adjacent unit cells. We introduce a function f∆(x, y) to represent the time delay contributed by the relative location of the unit cell with position deviation (x, y) to the center of unit metasurface structures.

f∆(x, y) =1
c

(|(x − 1) sin θ cos ϕ + (y − 1) sin θ sin ϕ − cos θ|

− |sin θ cos ϕ + sin θ sin ϕ + cos θ|).
| (6)
If the relative positions of the four elements related to the center of the unit cell are fixed, the advance in time can be defined as positive and the delay in time can be defined as negative. Therefore, f∆(x, y) can be reduced to

f∆(x, y) = −

1
c

(x sin θ cos ϕ + y sin θ sin ϕ). (7)

Then the equation for modifying the four tmn,i functions
π
2

, π, 3π
2

) can be simplified into a more general form with the value of τ remains unchanged, i.e.,

t

i

′
mn = t

i
mn − f∆(xi
, yi) | (8)

where (xi

, yi) is the relative position of each unit cell.


Fig. 2. Structure of C-shape metasurface unit structure with h={0.035, 0.018, 0.035, 0.018} mm, w={0.96, 0.84, 0.96, 0.84} mm, β={18, 108, 18, 108}◦, α={45, 45, -45, -45}◦, r = 7.2 mm, D = λ/4 and hsub=16 mm. Here the four parameters of all the data correspond to the unit cell perform 0,

| π
| 2 , π, 3π
| 2 phase shift. Each
unit cell contains two pin diodes controlled by the time modulation signals.
B. Unit Metasurface Structure Design

In this section, four 1-bit C-shape programmable metasurface elements with different phase responses are designed, as shown in Fig. 2. The unit cell structure is designed to be fabricated on a roger printed circuit board with a top copper thickness h, a subtrate thickness of hsub, and a dielectric constant of 3.66. The split-ring-resonator (SRR) inspired meta-element is designed to operate at a frequency of 4.2 GHz with a inner diameter r and thickness
w. Chosen parameters can be found in the caption of Fig. 2. Two PIN diodes controlled by a micro-controller are added to each SRR to realize fast and independent element modulation. Through the design of opening angle β and orientation angle α, different phase modulation values can be realized. Four "ON" states with different phase shifts can be achieved by turning on the corresponding unit cell while turning off the reminders, and the "OFF" state can be produced by turning off all pin diodes.
Simulation results performed through CST Microwave Studio are shown in Figs. 3(a) and 3(b), which show the cross-pol transmittance and phase shift responses of the unit structure. Bandwidth is defined as the frequency range in which the "ON"-"OFF" ratio is greater than 20 dB and the relative error angle is less than 10◦
. At
the operating frequency, 4.21 GHz, the simulation results

( i = 0,

## As shown on fig 2,... yinchu D

such that a combination of the transmissive electromagnetic waves modulated by the modulating pulses leads to suppression of undesired harmonics [4]. We first consider the modulation sequence of metasurface with negligible inter-cell distance, and then the impact of particular cell arrangement is further analyzed. The length of each meta-element is defined as D. We first simplify all four meta-element are at the same location. Suppose that the origin is defined at the center of the bottom left unit structure and the whole metasurface totally have M rows and N columns, then the coordinate of the unit structure on the mth row and nth column under the ideal case can be defined as

Bandwidth; Frequency (GHz); Normalized Amplitude (dB); OFF; Phase Shift (; Normalized Gain (dB)

0 | 0.5 | 1 | 1.5

1

3

5

8

10

Normalized Element On-Time

Element

(c)

-90 -60 -30 | 0 | 30 | 60 | 90

-35

-30

-20

-10

Angle (◦
)

(d)

Fig. 3. Simulated characteristics of unit metasurface structure. (a) The S21 parameter of the five states. From 4.19 GHz to 4.39 GHz, the S21 parameter for "ON" states is larger than -13 dB and S21 parameter for the "OFF" state is less than -30dB. And the minimal amplitude response for "OFF" state is -66 dB. (b) The four different phase shift responses. From 4.14 GHz to 4.35 GHz, the average relative error angle is less than 10◦. (c) The switch control signal for STPM unit cells at the position d11, d12 and d13 where blue means the pin diode is on.
(d) Simulated radiation patterns for different harmonics generated by STPM at the target angle of 20◦.

show that within the bandwidth, the average "ON"-"OFF"
ratio is 27.6 dB and the average relative error angle for
the phase shift of four "ON" states is less than 10◦

III. Simulation Result
Simulation is performed to validate the STPM method with D = λ/4, targeted angle 20◦ and operating frequency 4.21 GHz. In order to simulate the ability of the STPM to form beam and suppress spurious bands, a binary image is transmitted through the time modulated metasurface. Fig. 3(c) gives a pictorial representation of the switch control signal of twelve metasurface unit cells at the position d11, d12, and d13. dmn is defined on (1) and the order of unit cells in the unit structure follows 0, π
2

,π ,

3π
2
The periodicity of the switch control signal and the offset between different unit structures can be clearly observed. Fig. 3(d) shows the normalized power on five different harmonics. The normalized power of the side band are all less than -15 dB and the power of the 1

st harmonic reaches
the maximum at our target angle.

IV. Conclusion

In this paper, a time modulated programmable metasurface structure and its control strategy is designed to ensure both flexibility and efficiency of beamforming and spurious bands suppression. The validity of the metasurface structure containing four "ON" states with different phase responses and one "OFF" state with low transmittance is shown by CST simulation and the control strategy of the STPM is tested by MATLAB which shows beamforming and undesired harmonic suppression abilities.

References

[1] S. Liu, T. J. Cui, L. Zhang, Q. Xu, Q. Wang, X. Wan, J. Q. Gu,
M. Qing Qi, J. G. Han et al., “Convolution operations on coding metasurface to reach flexible and continuous controls of terahertz beams,” Advanced Science, vol. 3, no. 10, p. 1600156, 2016.
[2] A. H. Abdelrahman, A. Z. Elsherbeni, and F. Yang, “Transmission phase limit of multilayer frequency-selective surfaces for transmitarray designs,” IEEE Transactions on Antennas and Propagation, vol. 62, no. 2, pp. 690–697, 2013.

[3] H. Rajabalipanah, M. H. Fakheri, and A. Abdolali, “Electromechanically programmable space-time-coding digital acoustic metasurfaces,” arXiv preprint arXiv:2003.12616, 2020.
[4] A.-M. Yao, W. Wu, and D.-G. Fang, “Single-sideband timemodulated phased array,” IEEE Transactions on Antennas and Propagation, vol. 63, no. 5, pp. 1957–1968, 2015.

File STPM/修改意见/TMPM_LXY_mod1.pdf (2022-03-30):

# High Efficiency beamforming Based on Time-Modulated Programmable Metasurface

Chengfan Li
UM-SJTU Joint Institute
Shanghai Jiao Tong University Shanghai 200240, China.

Xuyang Lu
UM-SJTU Joint Institute
Shanghai Jiao Tong University Shanghai 200240, China.
corresponding author:
xuyang.lu@sjtu.edu.cn

Abstract—In this paper, a time-modulated transmitive programmable metasurface structure and its corresponding control strategy is designed to achieve beamforming and spurious bands suppression.
Index Terms—Programmable Metasurface, Time-Modulated Array, Single-Sideband.
I. Introduction

Recently, the possibility for metasurface to engineer electromagnetic (EM) space and manipulate the EM wave propagation by tailoring permittivity and permeability arbitrarily has received wide attention. The application of metasurface spreads among beamforming [1] and communication [2]. then? may be focus on the advantages for Meta to achive beamforming However, metasurface faces the trade-off between flexibility and efficiency, especially in beamforming. The less states a metasurface cell has, the higher its energy efficiency and accuracy, but in this case the direction of the formed beam is limited. On the other hand, too many states will increase the harmonic waves, leading to the efficiency degradation and the crosstalk problem. grammar? will cause a increase of undesired harmonics, leading to blabla On the other hand, beamforming is achieved through the time-modulated array by exploiting time-domain signal processing techniques [3]. To achieve a low sideband level (SBL), the switching sequence can be designed such that a combination of signals modulated by those pulses will lead to suppression of undesired harmonics [4].
In this paper, as shown on Fig. 1, a time-modulated programmable metasurface (TMPM) is designed to apply the time modulated method on metasurface to achieve both flexibility and efficiency on beamforming grammar. Each unit structure has four on state with phase shift 0, π
2

,π,

3π
2

and one off state with low transmittance. connection? talk about your design for the "flexibility and efficiency" discussed in the first para

II. Design and Theory

A. Unit Metasurface Structure Design

A metasurface structure with five states which is on state with ϕ = (0, π
2

,π,

3π
2

) phase shift and an off state need


Fig. 1. Architecture of TMPM.


Fig. 2. Structure of C-shape metasurface unit structure with h={0.035, 0.018, 0.035, 0.018}mm, w={0.96, 0.84, 0.96, 0.84}mm, β={18, 108, 18, 108}◦, α={45, 45, -45, -45}◦, r=7.2mm and hsub=16mm. Here the four parameters of all the data correspond to the unit cell perform 0, π

| 2 ,π, 3π
| 2 phase shift.

to be designed. After applying time modulated method, we do not need to design the complex 3-bit metasurface structure which is hard to ensure efficiency. But only need to design four 1-bit metasurface unit cells to provide different phase shifts, and then combine them together to form a unit structure. move those description in the into? till now, readers do not know that is time modulation Here, we design four different C-shape programmable metasurface unit cells, and form a metasurface unit structure. do not use we The improved structure is shown on Fig. 2. On the top layer is four thin copper rings with

Frequency (GHz); Normalized Amplitude (dB); OFF; Phase Shift (

Fig. 3. Simulated characteristic of unit metasurface structure. (a) The S12 parameter of the five states. (b) The four different phase shift responses.

height h, inner diameter r and thickness w. Under the
ring is a substrate with thickness hsub, side length λ/D and material Rogers RO4350B. Two MA4AGFCP910 pin diodes produced by MACOM are added on each metal ring to realize the programmable function, and FPGA is used to control the fast switch of each unit cell independently to realize the time modulation. Through the design of opening angle β and orientation angle α towards the xaxis, phase modulation can be realized.

Then Remove then the simulation results of our structure are given by CST Microwave Studio. Fig. 3 shows the transmittance and phase shift responses of the unit structure. combine them into a sentence At the operating frequency which is 4.21GHz .....grammar, the simulation results show an obvious transmittance difference between the on and off states, and four phases with separation of approximately π
2

in the four on states "ON" states.

B. Time Modulated Metasurface Principle

what’s out goal In ideal situation, each unit structure can be viewed as an array element which means that the distance λ/2D between two unit cells vanishes. ? I don’t get that

Suppose that the origin is defined at the center of the bottom left unit structure and the whole metasurface totally have M rows and N columns, then the position of the unit structure on the m-th mth row and n-th column under the ideal case can be defined as remove imperative sentence
dmn = (mλ/D, nλ/D, 0). | (1)

So the array factor can be written as

AF(θ, ϕ, t) = f(t)

∑

M

m=1

∑

N

n=1

Imn · Umn

- e

j

2π
D sin θ[(m−1) cos ϕ+(n−1) sin ϕ]
(2)
where θ and ϕ defines the aimed angle for beamforming, ,f(t) denotes the incident wave, Imn is the transmittance for the unit structure on position dmn and Umn is the control function for the unit structure on position dmn. Because each unit structure contains four unit cells, Umn can be further written as

Umn = U

0
mn(t) + jU

π
2mn(t) − U

π
mn(t) − jU

3π
2mn(t) (3)

where U

0
mn(t), U

π
2mn(t), U

π
mn(t) and U

3π
2mn(t) are control
function on unit cell with different phases.

The control signal consists of square wave so that the control functions U

i
mn(i = 0,

π
2

, π, 3π
2

) can be further
writtern as

Umn,i(t) = rect(

t − τ /2 − kTp − t

i
mn
τ
) | (4)

where Tp is the period of the switch control signal, τ is the time when the switch is on and t

i
mn is the time delay.

For each unit structure, the four cells’ time delay and τ can be writtern as

t

π
2mn = t

0
mn +

Tp
4

t

π
mn = t

0
mn +

Tp
2

t

3π
2mn = t

0
mn −

Tp
4

τ =

Tp
3

2 | 4 | 6 | 8 | 10 | 12

0

0.5

1

1.5

Element

Normalized Element On-Time

Fig. 4. The switch control signal for TMPM

Angle (; Normalized Power (dB)

Fig. 5. Simulated radiation patterns for different harmonics generated by TMPM

where

t

0
mn = {

sin θ
D

[(m − 1) cos ϕ + (n − 1) sin ϕ] −

1
6

}Tp. (5)

Then the interval between unit cells can be considered. We can define a function f∆(x, y) to represent the time delay caused by the unit cell position deviation (x, y). then.... we....

f∆(x, y) = |(x − 1) sin θ cos ϕ + (y − 1) sin θ sin ϕ − cos θ| − |sin θ cos ϕ + sin θ sin ϕ + cos θ| . (6)
For the relative position of the four unit cells related to the center of the unit metasurface structure is fixed, we can suppose that the advance of time is defined as positive and the delay of time is defined as negative. So that ( [?]) can be modified into
f∆(x, y) = −x sin θ cos ϕ − y sin θ sin ϕ. | (7)

Then the equation for modifying the four tmn,i functions (i = 0,

π
2

, π, 3π
2

) can be simplified into a more general form. And the value of τ remains unchanged.

t

i

′
mn = t

i
mn − f∆(xi
, yi) | (8)

where i = 0,

π
2

, π, 3π
2

, (xi

, yi) is the relative position of each unit cell, for example, (x1, y1) = ( λ
4D

,

λ
4D

).

III. Simulation Result

Simulation is performed to validate the TMPM method with T=4, targeted angle 20◦ and operating frequency 4.21GHz. In order to simulate the ability of the TMPM to form beam and suppress spurious bands, a binary image is modulated and transmitted through the time modulated metasurface.
Fig. 4 gives a pictorial representation of the switch control signal of twelve metasurface unit cells at the position d11, d12 and d13. The periodicity of the switch control signal and the offset between different unit structures can be clearly observed. Fig. 5 shows the normalized power on five different harmonics. The normalized power of the side band are all less than -18dB and the power of the 1st harmonic reaches the maximum at our target angle.

IV. Conclusion
In this paper, a time modulated transmitive programmable metasurface structure and its corresponding control strategy is designed to achieve beamforming and spurious bands suppression. The CST simulation is provided to ensure the validity of the characteristic of the structure and the Matlab is used to test the control strategy of the metasurface array. Both the two simulation shows excellent results in line with our expectation.....be specificc Introducing time modulation into metasurface can ensure the flexibility and efficiency of beamforming, namely, use less states for each unit cell to perform more complex functions.to solve blabla problem, TM technique blabla

References

[1] L. Bao, R. Y. Wu, X. Fu, Q. Ma, G. D. Bai, J. Mu, R. Jiang, and T. J. Cui, “Multi-beam forming and controls by metasurface with phase and amplitude modulations,” IEEE Transactions on Antennas and Propagation, vol. 67, no. 10, pp. 6680–6685, 2019.
[2] L. Zhang, M. Z. Chen, W. Tang, J. Y. Dai, L. Miao, X. Y. Zhou,
S. Jin, Q. Cheng, and T. J. Cui, “A wireless communication scheme based on space-and frequency-division multiplexing using digital metasurfaces,” Nature Electronics, vol. 4, no. 3, pp. 218– 227, 2021.
[3] H. Shanks and R. Bickmore, “Four-dimensional electromagnetic radiators,” Canadian Journal of Physics, vol. 37, no. 3, pp. 263– 275, 1959.
[4] A.-M. Yao, W. Wu, and D.-G. Fang, “Single-sideband time-modulated phased array,” IEEE Transactions on Antennas and Propagation, vol. 63, no. 5, pp. 1957–1968, 2015.

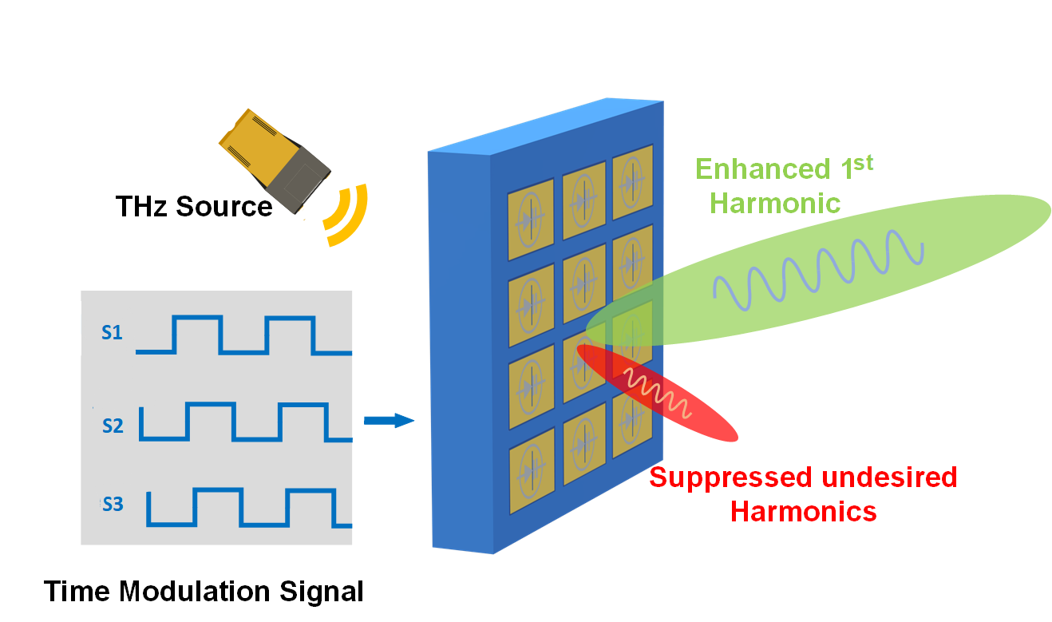
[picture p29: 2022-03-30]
STPM/TMPM_figure/概念图最终稿/gnt.png

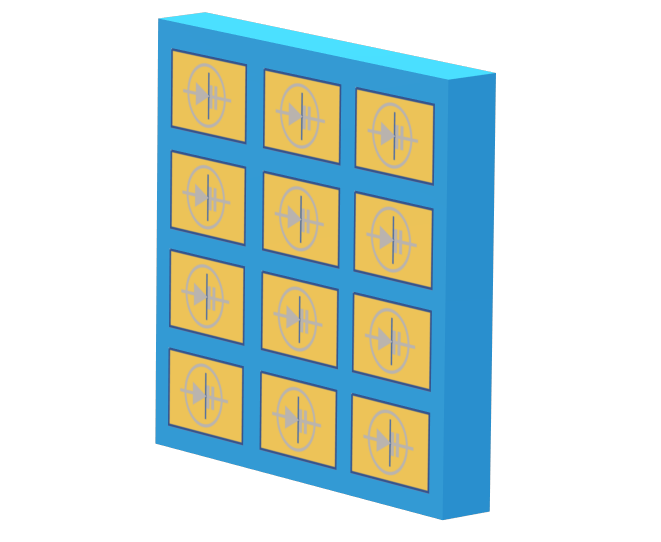
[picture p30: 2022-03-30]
STPM/TMPM_figure/概念图/TMPM.png

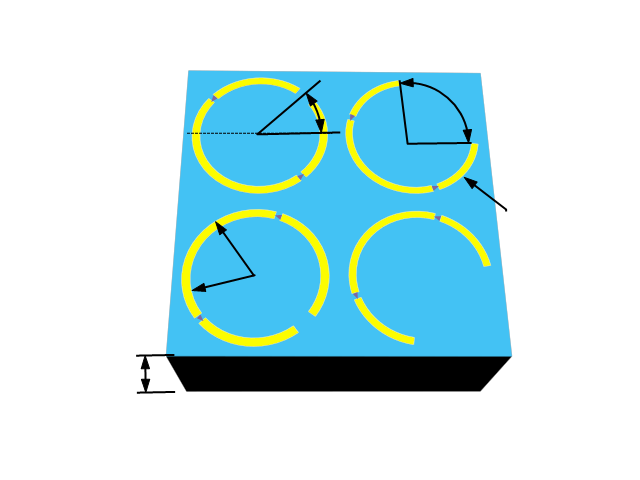
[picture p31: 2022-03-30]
STPM/TMPM_figure/3D_Res/forps_new.png

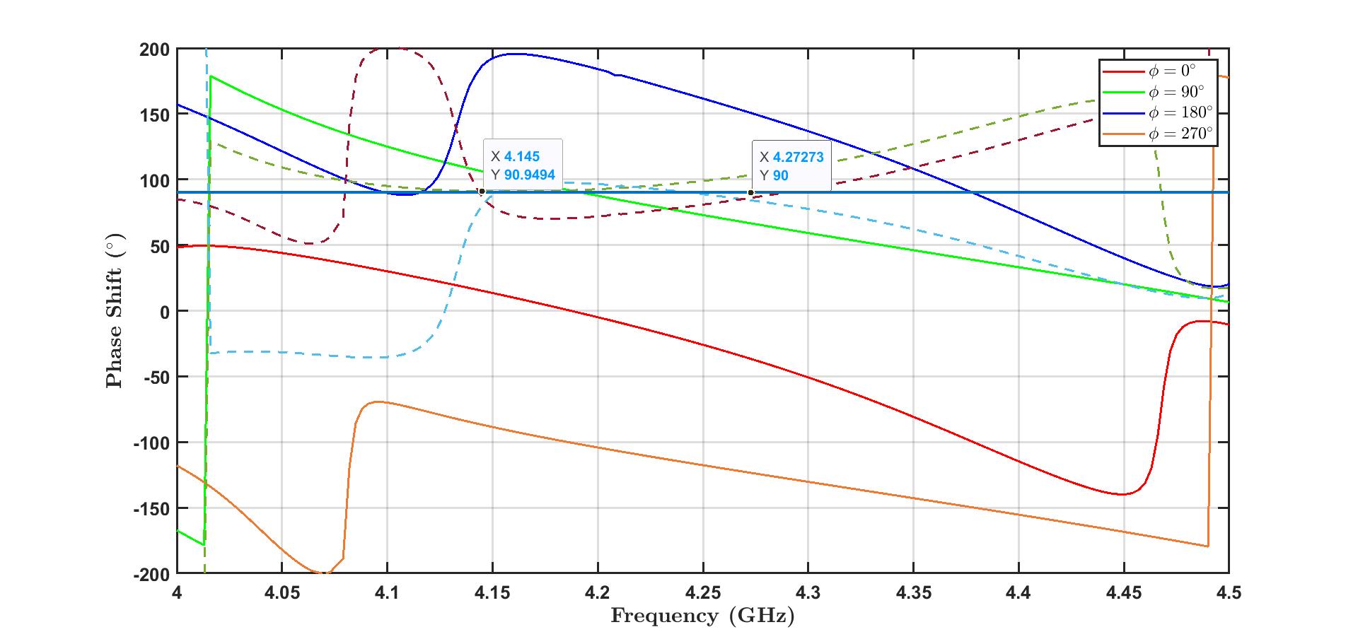
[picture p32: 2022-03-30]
STPM/TMPMre/houlai/phase_compare.jpg

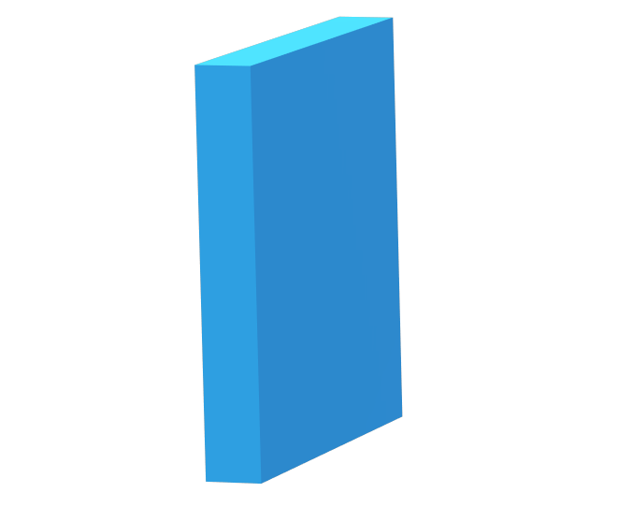
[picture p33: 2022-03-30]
STPM/TMPM_figure/概念图/false.png

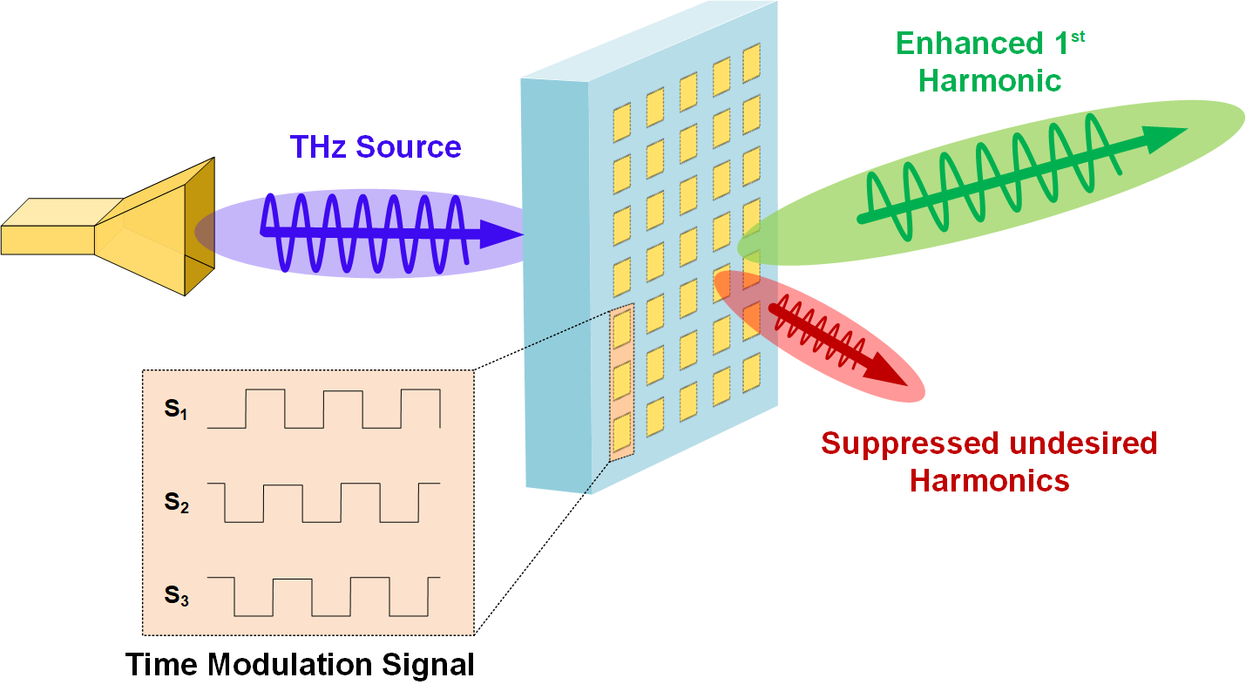
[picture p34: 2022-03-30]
STPM/老师改了之后/gnt.png

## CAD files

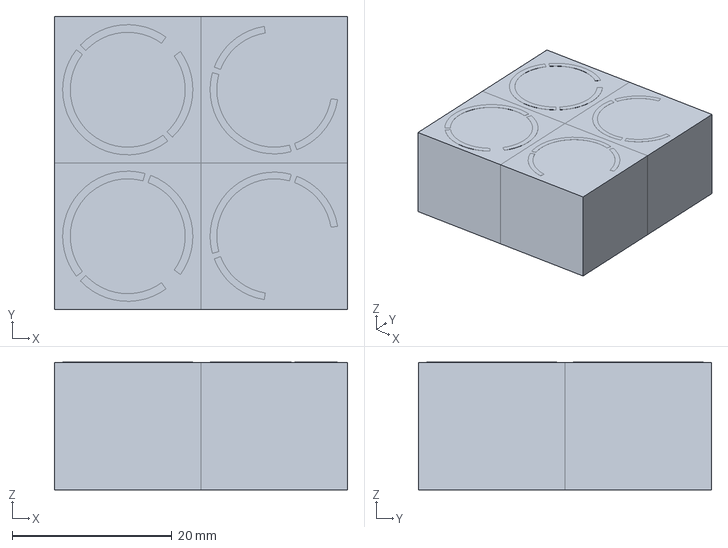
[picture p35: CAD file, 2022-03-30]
STPM/TMPM_figure/3D/newColor/newcolor.igs
36.7 x 36.7 x 16.0 mm

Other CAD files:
STPM/TMPM_figure/3D/oo.igs

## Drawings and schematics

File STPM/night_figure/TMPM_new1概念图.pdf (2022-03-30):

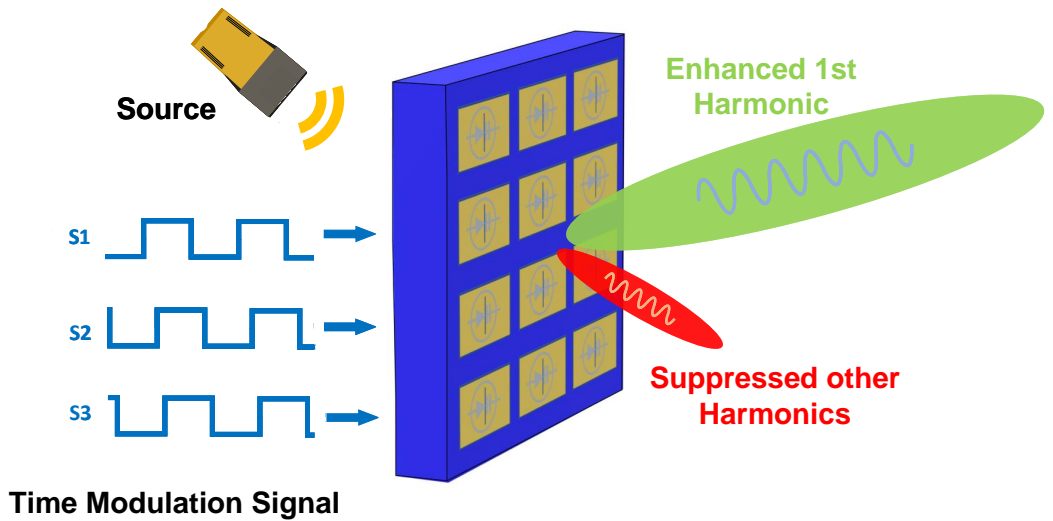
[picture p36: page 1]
Suppressed other Harmonics; Enhanced 1st Harmonic; Source

Time Modulation Signal

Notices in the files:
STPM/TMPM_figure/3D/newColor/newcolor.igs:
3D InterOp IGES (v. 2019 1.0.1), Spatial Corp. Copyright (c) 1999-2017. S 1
